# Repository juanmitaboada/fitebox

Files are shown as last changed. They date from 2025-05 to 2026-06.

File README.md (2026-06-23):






# FITEBOX - Autonomous Conference Recording Appliance

**Record every room. Spend almost nothing. Keep full control.**

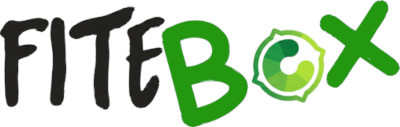
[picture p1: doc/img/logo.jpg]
Fitebox logo


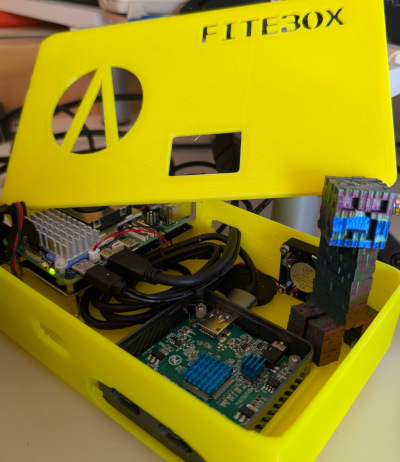
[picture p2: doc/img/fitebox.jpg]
Fitebox


**FITEBOX** is an open-source recording box built on a Raspberry Pi 5 that captures conference talks autonomously - composite video (slides + speaker camera), mixed audio, branded overlays, and optional live streaming to YouTube or Twitch - all managed from a tiny OLED screen on the box or a web UI on your phone.

One box per room. A volunteer plugs it in before the first talk, collects recordings at the end of the day. No dedicated operator, no laptop, no cloud dependency.

```
  License .... Apache 2.0
  Status ..... Production-ready - deploying at OpenSouthCode 2026, Málaga
  Authors .... Juanmi Taboada, David Santos
  Repository . https://github.com/juanmitaboada/fitebox
```

---

## Table of Contents

  1. [Why FITEBOX Exists](#1-why-fitebox-exists)
  2. [What You Get](#2-what-you-get)
  3. [Hardware Requirements](#3-hardware-requirements)
  4. [Quick Start](#4-quick-start)
  5. [Software Setup](#5-software-setup)
  6. [First Boot](#6-first-boot)
  7. [Documentation](#documentation) - Configuration, Recording, Streaming, Architecture, Troubleshooting, API
  8. [Project](#project) - Changelog, Contributing, Code of Conduct, Security Policy
  9. [Credits & Acknowledgments](#credits--acknowledgments)
  10. [License](#license)

---

## 1. Why FITEBOX Exists

Community tech conferences run on volunteer time and sponsor money. Recording talks is essential - speakers deserve an audience beyond the room, and attendees want to revisit sessions they missed - but professional recording services eat budgets alive. We know because it happened to us.

[OpenSouthCode](https://www.opensouthcode.org) is an annual open-source conference in Málaga, Spain. For years, hiring recording crews consumed up to **40% of the total event budget**. That is money not going to making the event better. For a non-profit association with limited funds, it was unsustainable.

In 2025, **David Santos** and **Juanmi Taboada** decided to fix this. David had the vision for the hardware: a small box based on a Raspberry Pi 5 with an OLED display and physical buttons, capable of autonomously recording a conference room. He designed the hardware architecture, selected the components (the SSD1306 OLED, the GPIO buttons, and the HDMI capture card - the same one used at FOSDEM conferences), and built the first physical prototype, including the 3D-printed enclosure. The hardware foundation of FITEBOX is David's work.

Both of us started developing software independently. We tried FFmpeg first, then OBS. We discovered the hard way that the Raspberry Pi 5 **has no hardware H.264 encoder** (the Pi 4 had `v4l2m2m` - the Pi 5 dropped it entirely). Cheap microphones died after 30 minutes. One of the units was handed to a volunteer with no user interface of any kind. OBS silently misconfigured itself. We lost nearly half the recordings from OpenSouthCode 2025.

But the idea was sound. One small box per room, fully autonomous, costing a fraction of a professional crew. After the event, Juanmi dove back in - this
time armed with patience, better tools, and a determination to make the Pi 5 work. Weeks of development followed: 36 versions of the recording engine, many manual tests on real hardware, and a complete web interface with real-time monitoring. FITEBOX grew from a rough experiment into a professional-grade recording and streaming system.

What you see in this repository is the result. It works. It has been tested.

**If your association, hackerspace, user group, or community conference needs to record talks without blowing the budget - this is for you.**

---

## 2. What You Get

All your videos properly recorded under a layout like this one:

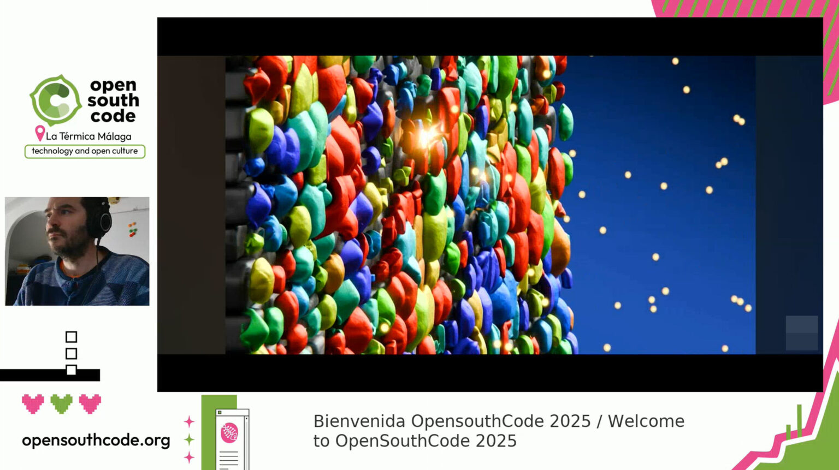
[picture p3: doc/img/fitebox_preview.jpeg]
Fitebox Video Layout


A fully configured FITEBOX gives you:

- **Composite 1080p recording** - presenter's screen (via HDMI capture) as the main image, speaker camera as picture-in-picture, your conference branding as the background frame, and talk title + speaker name as text overlays.

- **Automatic audio mixing** - room microphone plus HDMI audio from the presenter's laptop, combined automatically. Plug in one mic or two sources,
  the system adapts.

- **Crash-resistant MKV files** - recordings survive power failures. Even if someone trips over the power cable, everything recorded up to that point is
  recoverable.

- **Web UI from your phone** - read the 6-character access key from the OLED screen, type it in your phone browser, and you have full control: start/stop recording, monitor health, preview the feed, manage files, configure everything.

- **OLED + physical buttons** - no phone needed for basic operation. Navigate  menus, start recording, check status, all from four buttons on the box.

- **Live streaming** - optional RTMP streaming to YouTube, Twitch, or any custom server. Branded intro/outro bumpers, single persistent connection,
  zero extra CPU cost for video (audio re-encoded to fix timestamp issues).

- **Conference schedule integration** - import your Frab/Pentabarf schedule XML (the standard used by FOSDEM, CCC, OpenSouthCode, and many others) and FITEBOX auto-fills talk titles and speaker names based on room and time.

- **Network flexibility** - connect to the venue WiFi, create its own hotspot if there is no WiFi, or use Ethernet. All configurable from the web UI or
  OLED menus.

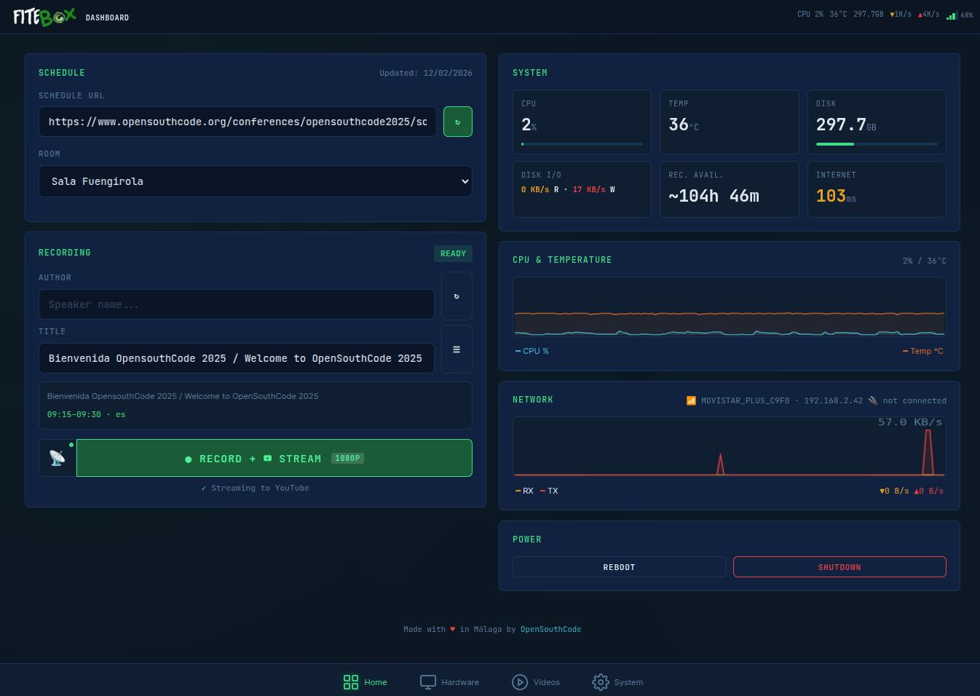
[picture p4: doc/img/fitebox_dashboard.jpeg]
Fitebox Web UI Dashboard


---

## 3. Hardware Requirements

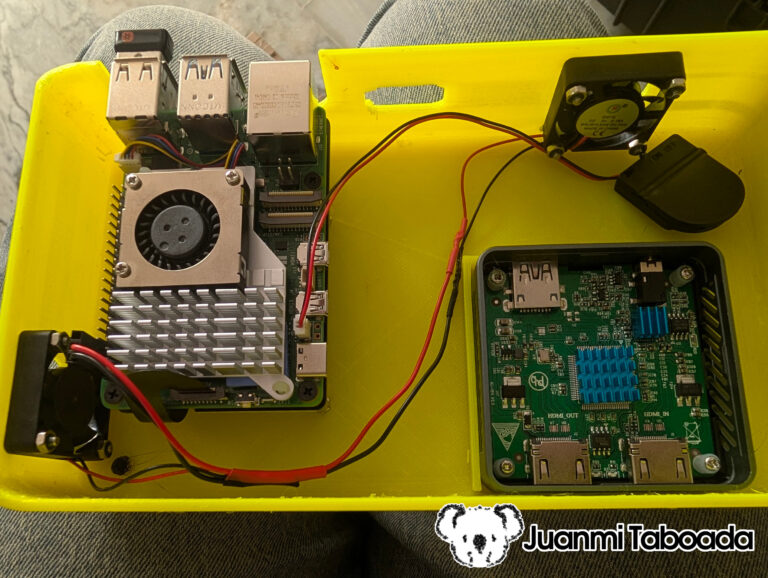
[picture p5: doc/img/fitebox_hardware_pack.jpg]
Fitebox Core Hardware


For a complete guide on assembling the hardware (mounting the NVMe HAT, installing the OLED+buttons module, building the enclosure), see the
companion build guide: [FITEBOX Build Guide - juanmitaboada.com](https://www.juanmitaboada.com/fitebox/)

---

## 4. Quick Start

If your hardware is assembled and your Raspberry Pi 5 is running **Raspberry Pi OS Lite (64-bit, Bookworm)**, this is all you need.

**1. Create the FITEBOX user** (from any account with sudo privileges — e.g. the default `pi` user):

```bash
sudo adduser osc
sudo usermod -aG sudo osc
```

> ⚠️ The user needs to be in the `sudo` group during installation. After the first boot, `setup.sh` automatically restricts sudo to only `reboot` and `shutdown` — no password needed for those.

**2. Log in as the new user:**

```bash
su - osc
# or reconnect via SSH as osc
```

**3. Download and run the installer:**

```bash
curl -fsSL https://raw.githubusercontent.com/juanmitaboada/fitebox/main/bin/install.sh -o install.sh
sudo bash install.sh
```

To install a specific version instead of `latest`:

```bash
sudo bash install.sh 1.2
sudo bash install.sh 1.2-rc1
```

The installer will:
- Download all required files (`setup.sh`, `docker-compose.yml`, `nginx.conf`)
- Install Docker, configure audio, optimize the kernel, and generate TLS certificates
- Pull the FITEBOX Docker image
- Start the containers
- Reboot the system (the OLED and display will show a reboot screen)

After reboot, FITEBOX starts automatically. Access the web UI at `https://<your-rpi-ip>`.

**To update to a new version**, use the web UI (System → Check for updates):

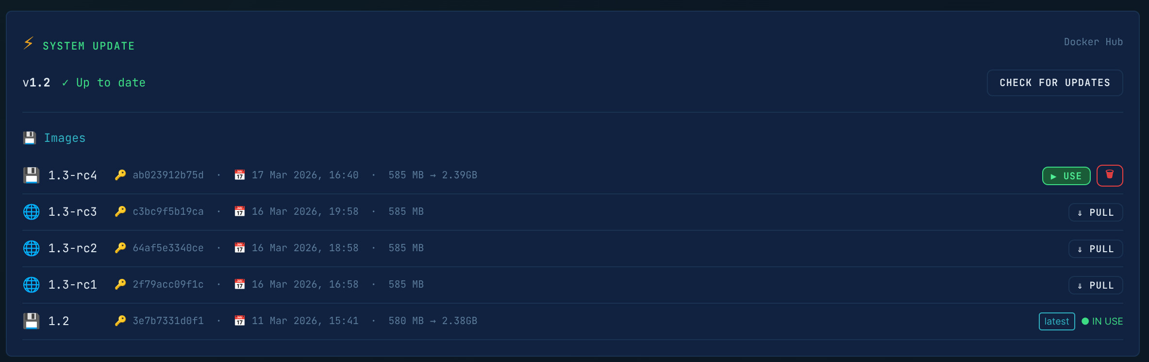
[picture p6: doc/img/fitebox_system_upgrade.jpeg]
Fitebox Upgrading System


**or run:**

```bash
cd ~/fitebox
docker compose pull
docker compose up -d
```

**To pin a specific version or test a pre-release**, edit `~/fitebox/docker-compose.yml` and change the image tag, then recreate the container:

```yaml
# Docker Hub
image: docker.io/br0th3r/fitebox:1.2
# GitHub Container Registry
image: ghcr.io/juanmitaboada/fitebox:1.2
# Pre-release
image: docker.io/br0th3r/fitebox:1.3-rc4
```

```bash
docker compose up -d --force-recreate recorder
```

Pre-release tags (`-rc`, `-beta`, `-alpha`, `-dev`) are published alongside stable releases but never replace `latest`.

---

## 5. Software Setup

### 5.1 Flash OS directly to the NVMe SSD

FITEBOX boots directly from the NVMe SSD - no SD card needed for daily use. Connect the NVMe SSD (via a USB adapter or the PCIe HAT on another Pi) and flash **Raspberry Pi OS Lite (64-bit, Debian 12 Bookworm)** to it using [Raspberry Pi Imager](https://www.raspberrypi.com/software/).

During setup in the Imager, enable:

- SSH (so you can work headless)
- Set hostname to something identifiable (e.g., `fitebox-room1`)
- Configure WiFi if needed for initial setup

After flashing, boot the Pi with a temporary SD card to configure PCIe and boot order:

```bash
sudo raspi-config
# → Advanced Options → PCIe Speed → Yes
#   (Enables the PCIe connector and forces Gen 3.0 speeds)

sudo raspi-config
# → Advanced Options → Boot Order → B1: SD Card Boot
#   (Boot from SD card if available, otherwise boot from NVMe)
```

Once configured, remove the SD card and the Pi boots from NVMe. Fast, reliable, and the full 500GB is available for both the OS and recordings.

SSH in and update:

```bash
sudo apt update && sudo apt upgrade -y
```

### 5.2 Enable I2C (for the OLED display)

> ✅ `setup.sh` now enables I2C automatically (`raspi-config nonint do_i2c 0`),
> so on a normal install you can skip this step. Do it by hand only if you need
> the OLED working **before** running `setup.sh`.

```bash
sudo raspi-config
# → Interface Options → I2C → Enable
```

Verify the OLED is detected (should show address `0x3c`):

```bash
sudo apt install -y i2c-tools
i2cdetect -y 1
```

The OLED+buttons integrated module connects to the GPIO header with an 8-wire ribbon cable:

| Module Pin | RPi Pin | GPIO |
|---|---|---|
| GND | 39 | Ground |
| VCC | 1 | 3.3V |
| SCL | 5 | GPIO3 (I²C) |
| SDA | 3 | GPIO2 (I²C) |
| K4 (Select) | 35 | GPIO19 |
| K3 (Down) | 38 | GPIO20 |
| K2 (Up) | 36 | GPIO16 |
| K1 (Back) | 37 | GPIO26 |

No external resistors needed - buttons use internal pull-ups via `gpiod`.

### 5.3 Create the recordings directory

Since the OS and recordings live on the same NVMe SSD, just create the recordings directory on the root filesystem:

```bash
sudo mkdir -p /recordings
sudo chown -R 1000:1000 /recordings
```

### 5.4 Build from Source (for development)

```bash
sudo apt-get install git
git clone https://github.com/juanmitaboada/fitebox.git
cd fitebox
make setup          # or: sudo ./bin/setup.sh
```

> ⚠️ **`make setup` is mandatory before your first `make up`.** Besides installing
> dependencies and configuring the Raspberry Pi, it **generates the self-signed TLS
> certificate** (`certs/fitebox.crt` / `certs/fitebox.key`) that the nginx proxy
> mounts. `make up` does **not** create it. If you skip setup and run `make up`
> directly, the `fitebox_proxy` container crash-loops with:
>
> ```
> nginx: [emerg] cannot load certificate "/etc/nginx/certs/fitebox.crt": ... No such file or directory
> ```
>
> (If you only need the certificate and not a full re-setup, generate it by hand:
> `mkdir -p certs && openssl req -x509 -nodes -days 3650 -newkey rsa:2048
> -keyout certs/fitebox.key -out certs/fitebox.crt -subj "/CN=fitebox.local"`.)

**A reboot is required** after setup ([what setup.sh does](#55-what-setupsh-does)).

After reboot, build and run:

```bash
make up_build       # build + start   (or: docker compose build && docker compose up -d)
```

From then on, `make up` / `make down` / `make logs` start, stop, and monitor the stack.

To publish your local build to the registries (maintainers only):

```bash
make publish
```

---

### 5.5 What setup.sh does

The setup script must be run with `sudo`. It detects the real user (via
`$SUDO_USER`) and performs the following:

1. Installs base tools: `curl`, `wget`, `git`, `build-essential`, `v4l-utils`,
   `alsa-utils`, `bc`, `jq`, and `i2c-tools` (for OLED detection with
   `i2cdetect`).
2. Installs Docker and the Compose plugin, adds your user to the `docker` group.
3. Disables PulseAudio and PipeWire system-wide (masks services, disables
   autospawn) so they do not block ALSA access.
4. Tunes USB buffers (`usbfs_memory_mb=1000`), kernel parameters
   (`vm.swappiness=10`, dirty ratios, scheduler), and file limits (65536).
5. Enables the **I2C** interface (required for the SSD1306 OLED at `0x3c`).
6. Configures the kernel command line (`cmdline.txt`): cgroups for Docker
   memory management, forced **HDMI output at 1080p60**, and a clean appliance
   display (no kernel logo, no blinking console cursor).
7. On Raspberry Pi 5: enables **PCIe Gen 3** for faster SSD throughput, forces
   the **4K page-size kernel** (`kernel=kernel8.img`) for software
   compatibility, and sets boot to console login required (disables autologin).
8. Installs the FITEBOX Plymouth boot splash theme (if `plymouth/` directory
   exists).
9. Configures passwordless sudo for `reboot`, `shutdown`, and Plymouth
   messages.
10. Creates the directory structure (`recordings/`, `log/`, `run/`) with
    correct ownership.
11. Generates self-signed TLS certificates for HTTPS.
12. Creates the `.env` file with your UID/GID so Docker containers create
    files owned by your user (not root).

All boot-file changes are **idempotent** — each parameter is added only if it is
missing, so the script is safe to re-run. See
[5.6 Boot configuration](#56-boot-configuration-what-each-parameter-does-and-why)
for what every parameter does and why.

### Container details

The container starts in **privileged mode** - it needs direct access to video
devices (`/dev/video*`), I2C (`/dev/i2c-*`), GPIO (`/dev/gpiochip*`), ALSA
audio (`/dev/snd/*`), and thermal sensors. This is not optional.

Persistent data is stored in Docker volumes mapped to:

| Volume | Purpose |
|---|---|
| `/recordings` | NVMe SSD - recorded files go here |
| `/fitebox/data` | Background image, bumpers, schedule, config |
| `/fitebox/config` | Authentication master key |
| `/fitebox/run` | Runtime state (sockets, PIDs, health) |
| `/fitebox/log` | Service logs |

### 5.6 Boot configuration: what each parameter does, and why

`setup.sh` manages two firmware files on the boot partition. It never rewrites
them wholesale and **never touches `root=` / `PARTUUID`** (that value is unique
to each SD card / SSD). Every parameter below is added **idempotently** — only
if it is missing — so re-running the script never duplicates anything.

**`/boot/firmware/config.txt`**

| Parameter | What it does | Why FITEBOX needs it |
|---|---|---|
| `dtparam=i2c_arm=on` | Enables the I2C bus on the GPIO header. | The SSD1306 OLED talks over I2C (address `0x3c`). Without it the `oled_controller` service cannot find the screen and dies on boot. |
| `dtparam=pciex1_gen=3` | Forces the PCIe connector to Gen 3 speed (RPi 5). | Full NVMe SSD throughput, so recording and disk writes never become the bottleneck. |
| `kernel=kernel8.img` | Loads the generic ARM64 kernel with a **4K** memory page size instead of the Pi 5 default `kernel_2712.img`, which uses **16K** pages. | The 16K-page kernel buys ~5% performance but breaks software that assumes 4K pages (segmentation faults, "unsupported page size", or programs refusing to start). FITEBOX's FFmpeg / V4L2 capture / Python stack is built and tested on 4K pages, so the tiny performance trade-off is well worth the stability. Verify after reboot with `getconf PAGESIZE` → `4096` = correct, `16384` = wrong kernel. |

**`/boot/firmware/cmdline.txt`** — a **single line**; parameters are
space-separated and appended to the end:

| Parameter | What it does | Why FITEBOX needs it |
|---|---|---|
| `cgroup_enable=cpuset cgroup_enable=memory cgroup_memory=1` | Enables memory/cpuset cgroups in the kernel. | Docker needs them to enforce per-container memory limits. |
| `video=HDMI-A-1:1920x1080M@60` | Pins the HDMI output to 1080p @ 60 Hz. | The display daemon owns the HDMI port for status screens; without a fixed mode the resolution is auto-negotiated and may come up wrong or blank on some monitors. |
| `logo.nologo` | Hides the Raspberry Pi kernel logos shown during boot. | A clean, appliance-like boot — no Linux branding on the projector. |
| `vt.global_cursor_default=0` | Disables the blinking text cursor on the console. | Stops the lone blinking cursor from showing through on the HDMI output between the boot splash and the application. |

> ℹ️ **Why not just edit the files by hand?** Because each box may have a
> different `PARTUUID`, a different monitor, and may be re-imaged often.
> `setup.sh` adds only the keys that are missing and leaves everything else —
> most importantly `root=` — untouched, so it is safe to run on any fresh image.
> A **reboot** is required for kernel-page-size, PCIe and `cmdline.txt` changes
> to take effect.

### 5.8 Diagnostics

Before your first recording, run the diagnostic tools to verify all hardware is detected:

```bash
# Full system diagnostic - generates a timestamped report in /tmp/
./src/diagnostics.sh

# Audio device detection - classifies all ALSA cards by type
./src/detect_audio.sh

# OLED display detection - scans I2C, runs visual tests
./src/detect_oled.sh

# Button test - verifies GPIO button wiring
python3 src/detect_buttons.py
```

`diagnostics.sh` checks: system info, Raspberry Pi thermal/throttle status, disk space, USB devices, video devices (`v4l2-ctl`), audio devices and levels,
PulseAudio/PipeWire status (should be disabled), I2C/OLED, running FITEBOX processes, Docker containers, health files, recent logs, kernel messages,
network, and CPU/memory. It works both on the host and inside the container.

`detect_audio.sh` classifies ALSA cards into categories (`hdmi_capture`, `webcam`, `sound_card`, `usb_mic`, `generic_usb`) and selects the best
microphone with a priority order: professional sound card > USB mic > generic USB > webcam (fallback). It has a dual mode: run it directly for a full
diagnostic, or source it from another script (like the recording engine) and it exports variables (`VOICE_DEV`, `HDMI_DEV`, `VOICE_CARD_ID`, etc.)
silently. If the HDMI capture and voice mic end up being the same device (which would cause "Device or resource busy"), it automatically disables
HDMI audio and falls back to voice-only mode.

`detect_oled.sh` scans the I2C bus, finds the OLED at `0x3C` or `0x3D`, checks Python dependencies (`luma.oled`, `Pillow`), and runs a series of
visual tests on the display: clear screen, full white, border, text, animation, and a final info screen. It even stops `oled_controller.py` if it is running (the OLED can only be controlled by one process) and restarts it afterwards.

`detect_buttons.py` uses the FiteboxHardware abstraction to test all 4 GPIO buttons in real-time - press a button and see it reported on screen with
PRESS/RELEASE events at 100Hz polling.

---

## 6. First Boot

When the container starts, four services come up in order:

1. **Display daemon** - takes over the HDMI output for status screens and announcements.
2. **OLED controller** - the display lights up with the FITEBOX logo, then shows the system status.
3. **FITEBOX manager** - starts polling hardware (CPU, temperature, disk, network) and broadcasting status.
4. **Web server** - FastAPI on port 8080, ready for connections.

### Reading the access key

Look at the OLED screen. Cycle through the status views using the Up/Down buttons until you see the **Web Key** screen. It shows a 6-character hex code
like `A1B2C3`.

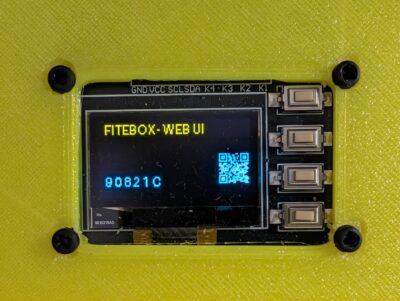
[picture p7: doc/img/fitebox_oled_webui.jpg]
Fitebox OLED Web UI Key


### Connecting to the web UI

On your phone or laptop, make sure you are on the same network as the FITEBOX (or connect to its hotspot if it created one). Open a browser and go to:

```
https://<FITEBOX_IP>
```

The OLED can also show a QR code with this URL - scan it with your phone camera for instant access.

Enter the 6-character key. You are in.

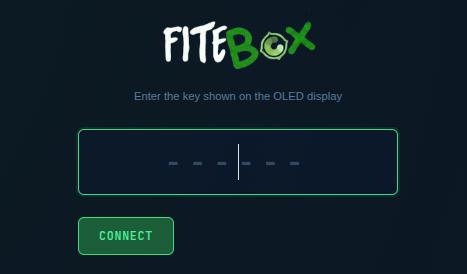
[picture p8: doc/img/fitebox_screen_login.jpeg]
Fitebox Web UI Login


---

## Documentation

  - [Configuration](doc/configuration.md) - Network, schedule, background, bumpers, diagnostics, security, self-update
  - [Recording a Talk](doc/recording.md) - Web UI, OLED buttons, engine internals, monitoring, announcements to projector
  - [Live Streaming](doc/streaming.md) - YouTube, Twitch, custom RTMP, single-connection architecture
  - [Managing Recordings](doc/recordings.md) - Playback, download, bumper concatenation, batch operations
  - [Architecture](doc/architecture.md) - Container layout, process communication, design decisions
  - [Troubleshooting](doc/troubleshooting.md) - Power, video, audio, encoding, OLED, USB, recovery
  - [API Reference](doc/api.md) - REST endpoints, WebSocket protocol, HMAC authentication
  - [Diagnostics Guide](doc/diagnostics.md) - How to use the diagnostic tools, interpret results, and fix common issues

---

## Project

  - [Changelog](CHANGELOG.md)
  - [Contributing](CONTRIBUTING.md)
  - [Code of Conduct](CODE_OF_CONDUCT.md)
  - [Security Policy](SECURITY.md)

---

## Credits & Acknowledgments

**David Santos** - designed the hardware architecture for the first FITEBOX prototype, selected the OLED display and button components, selected the HDMI capture card (the same one used at FOSDEM conferences), built the preliminary OLED controller software, and designed and 3D-printed the first physical enclosure (STL files included in the repository). The hardware foundation of this project exists because of David's work.

**Juanmi Taboada** - software development: recording engine (36 versions), streaming pipeline, web interface, system manager, OLED controller v2+, CPU optimization, setup automation, and all the FFmpeg debugging that led to production stability.

**[OpenSouthCode](https://www.opensouthcode.org)** - the annual open-source conference in Málaga, Spain, where FITEBOX was conceived, developed, and will be deployed in production at the 2026 edition. The need to record every room affordably and reliably is the reason this project exists.

This project was developed with assistance from AI coding tools (Claude by Anthropic, Gemini by Google) as pair-programming partners during the development process.

**Build guide & full story:** [juanmitaboada.com/fitebox](https://www.juanmitaboada.com/fitebox/)

**Docker images:** [GitHub Container Registry](https://ghcr.io/juanmitaboada/fitebox) · [Docker Hub](https://hub.docker.com/r/juanmitaboada/fitebox)

---

## License

```
Copyright 2025-2026 Juanmi Taboada, David Santos

Licensed under the Apache License, Version 2.0 (the "License");
you may not use this file except in compliance with the License.
You may obtain a copy of the License at

    http://www.apache.org/licenses/LICENSE-2.0

Unless required by applicable law or agreed to in writing, software
distributed under the License is distributed on an "AS IS" BASIS,
WITHOUT WARRANTIES OR CONDITIONS OF ANY KIND, either express or implied.
See the License for the specific language governing permissions and
limitations under the License.
```

---

*FITEBOX - because every talk deserves to be recorded, and no community
should go broke doing it.*

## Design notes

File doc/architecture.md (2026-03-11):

[← README](../README.md) · [Configuration](configuration.md) · [Recording](recording.md) · [Streaming](streaming.md) · [Recordings](recordings.md) · 【 **Architecture** 】 · [Troubleshooting](troubleshooting.md) · [API](api.md) · [Diagnostics](diagnostics.md)

## Architecture Overview

FITEBOX runs as two Docker Compose services. The main container holds all
application logic; a second container provides HTTPS termination:

| Service | Container | Role |
|---|---|---|
| `recorder` | `fitebox-recorder` | Main app — privileged, all FITEBOX logic |
| `proxy` | `fitebox-proxy` | nginx:alpine — HTTPS + WebSocket proxy |

Inside the **recorder** container, Supervisord manages four long-running
processes. The recording engine is launched on demand as a subprocess:

```
fitebox-recorder (privileged, network_mode: host)
│
│  Supervisord
│  ├── fitebox_display.py   ── Framebuffer display daemon (/dev/fb0)
│  ├── oled_controller.py   ── OLED + GPIO + Unix socket SERVER (hub)
│  ├── fitebox_manager.py   ── coordinator, launches recording engine
│  └── fitebox_web.py       ── FastAPI :8080, REST + WebSocket
│
│  On demand (subprocess of manager):
│  └── recording_engine.sh  ── FFmpeg composite → MKV + health.json
│
│  Communication:
│  oled_controller   ←── serves ──→  Unix Socket (.sock)
│  fitebox_manager   ←── client ──→  Unix Socket
│  fitebox_web       ←── client ──→  Unix Socket
│  fitebox_display   ←── serves ──→  Display Socket (.sock)
│  fitebox_web       ←── reads  ──→  MKV files + health.json
│
fitebox-proxy (nginx:alpine)
│  443 (HTTPS) → proxy_pass → 127.0.0.1:8080
│  80  (HTTP)  → redirect   → 443
```

The **OLED controller** owns the Unix domain socket and acts as the message
hub. The manager and web server connect as clients. When the manager sends a
status update, the OLED controller broadcasts it to all connected clients,
including the web server which pushes it to browsers via WebSocket.

The **display daemon** manages the HDMI output via `/dev/fb0`, replacing
Plymouth for runtime screen management. It pre-loads all screen images at
startup using numpy-accelerated RGB565 conversion (~0.3s), then idles at 0%
CPU until a message arrives on its Unix socket. It supports screen changes,
text overlays, and announcement overlays with flashing borders and
auto-scaled text.

The **manager** launches the recording engine as a subprocess on demand. The
web server reads from the MKV file and health logs produced by the engine
(for preview, health histogram, and streaming) but does not control it
directly.

**Key design decisions:**

**Why MKV?** Because it is the most crash-resistant container format. FFmpeg
writes Matroska clusters incrementally. If the process dies, you lose at most
the last few seconds, not the entire file.

**Why not microservices?** A Raspberry Pi is not a Kubernetes cluster. One
container with all services, communicating over a Unix socket, is simpler to
deploy, debug, and maintain. It starts faster and uses less memory.

**Why `ultrafast` preset?** The Pi 5 CPU is barely fast enough for real-time
1080p software encoding. The `ultrafast` preset trades file size for encoding
speed. At CRF 28 the quality is good enough for conference recordings and the
bitrate (~2.4 Mbps) is modest.

**Why software encoding at all?** Because the Raspberry Pi 5 has no hardware
H.264 encoder. The Pi 4 had `v4l2m2m` but the Pi 5 dropped it. This is the
single biggest design constraint of the entire project.

[← README](../README.md) · [Configuration](configuration.md) · [Recording](recording.md) · [Streaming](streaming.md) · [Recordings](recordings.md) · 【 **Architecture** 】 · [Troubleshooting](troubleshooting.md) · [API](api.md) · [Diagnostics](diagnostics.md)

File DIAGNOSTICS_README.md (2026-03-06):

# FITEBOX - Universal Diagnostics System

## Overview

The `diagnostics.sh` script works both on the **host** (Raspberry Pi) and inside the **Docker container**.

It auto-detects its environment and adapts the available commands accordingly.

---

## Usage

### On the HOST (Raspberry Pi):

```bash
cd ~/fitebox
./src/diagnostics.sh
```

### Inside the CONTAINER:

```bash
# Option 1: Execute from the host
docker exec fitebox-recorder /app/diagnostics.sh

# Option 2: Enter the container
docker exec -it fitebox-recorder bash
./diagnostics.sh
```

---

## What It Checks

### Always available (host + container):
- System information (OS, kernel, CPU, RAM)
- Disk space
- FITEBOX processes (FFmpeg, manager, OLED, web server)
- State files and logs
- Network configuration
- CPU/memory usage

### Host only:
- Raspberry Pi status (temperature, throttling, voltage)
- systemd services
- System configuration (PulseAudio, USB buffers)
- Docker container status

### Container only:
- Container environment info
- Volume mounts

### Requires privileges/devices:
- USB devices (`lsusb`) → requires `/dev/bus/usb`
- Video devices (`v4l2-ctl`) → requires `/dev/video*`
- Audio devices (`arecord`, `amixer`) → requires `/dev/snd`
- I2C (`i2cdetect`) → requires `/dev/i2c-*`
- Kernel messages (`dmesg`) → requires `CAP_SYSLOG`

---

## Docker Configuration

### Required system packages (in Dockerfile):
- `bc` - calculations for monitor
- `jq` - JSON parsing
- `usbutils` - lsusb
- `v4l-utils` - v4l2-ctl
- `alsa-utils` - arecord, amixer
- `i2c-tools` - i2cdetect
- `net-tools` - ifconfig
- `iproute2` - ip

### docker-compose.yml requirements:

**Device access:**
```yaml
devices:
  - /dev/video0:/dev/video0  # Cameras
  - /dev/snd:/dev/snd        # Audio
  - /dev/i2c-1:/dev/i2c-1    # OLED
  - /dev/gpiomem:/dev/gpiomem # Buttons
```

**Volumes for diagnostics:**
```yaml
volumes:
  - /dev/bus/usb:/dev/bus/usb:ro  # USB info
  - /proc:/host/proc:ro            # System info
  - /sys:/host/sys:ro              # Hardware info
  - /tmp:/host/tmp                 # Shared logs
```

**Privileged mode:**
```yaml
privileged: true  # Full hardware access
```

---

## Output

The script generates a timestamped report in `/tmp/`:
```
/tmp/fitebox_diagnostic_YYYYMMDD_HHMMSS.txt
```

### View from the host:
```bash
# If executed inside the container
docker exec fitebox-recorder cat /tmp/fitebox_diagnostic_*.txt

# Copy to host
docker cp fitebox-recorder:/tmp/fitebox_diagnostic_20260206_120000.txt .
```

---

## Troubleshooting

### Problem: "lsusb failed"
**Solution**: Verify `/dev/bus/usb` is mounted:
```bash
docker exec fitebox-recorder ls -la /dev/bus/usb
```

### Problem: "v4l2-ctl failed"
**Solution**: Verify video devices:
```bash
docker exec fitebox-recorder ls -la /dev/video*
```

### Problem: "arecord failed"
**Solution**: Verify `/dev/snd`:
```bash
docker exec fitebox-recorder ls -la /dev/snd
```

### Problem: "dmesg not accessible"
**Solution**: This is normal inside a container without `CAP_SYSLOG`. Run on the host instead:
```bash
dmesg | grep -i fitebox
```

---

## Rebuilding the Container

After updating the Dockerfile:

```bash
cd ~/fitebox

# Stop containers
docker compose down

# Rebuild
docker compose build --no-cache

# Start
docker compose up -d

# Verify
docker exec fitebox-recorder /app/diagnostics.sh
```

---

## Validation

### Quick test:

```bash
# On the host
./src/diagnostics.sh | grep "Environment:"
# Should show: Environment: host

# In the container
docker exec fitebox-recorder /app/diagnostics.sh | grep "Environment:"
# Should show: Environment: container
```

### Commands that MUST work in both environments:

| Command | Host | Container |
|---|---|---|
| Basic system info | ✅ | ✅ |
| Disk space | ✅ | ✅ |
| Processes | ✅ | ✅ |
| Network | ✅ | ✅ |
| `lsusb` | ✅ | ✅* |
| `v4l2-ctl` | ✅ | ✅* |
| `arecord` | ✅ | ✅* |
| `i2cdetect` | ✅ | ✅* |
| `vcgencmd` | ✅ | ❌ |
| `systemctl` | ✅ | ❌ |

\* Requires devices mounted correctly

---

## Usage Examples

```bash
# 1. Run full diagnostic
docker exec fitebox-recorder /app/diagnostics.sh

# 2. Search for specific problems
docker exec fitebox-recorder /app/diagnostics.sh | grep -i "error\|fail\|warn"

# 3. Audio devices only
docker exec fitebox-recorder /app/diagnostics.sh | grep -A 20 "AUDIO DEVICES"

# 4. Video devices only
docker exec fitebox-recorder /app/diagnostics.sh | grep -A 20 "VIDEO DEVICES"

# 5. Save and share
docker exec fitebox-recorder /app/diagnostics.sh > diagnostic_$(date +%Y%m%d).txt
```

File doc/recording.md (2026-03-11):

[← README](../README.md) · [Configuration](configuration.md) · 【 **Recording** 】 · [Streaming](streaming.md) · [Recordings](recordings.md) · [Architecture](architecture.md) · [Troubleshooting](troubleshooting.md) · [API](api.md) · [Diagnostics](diagnostics.md)

## Recording a Talk

### From the web UI

1. Open the **Dashboard**.
2. Verify the current talk is shown (if schedule is loaded).
3. Verify cameras and audio on the **Hardware** page - you can see live MJPEG previews of both cameras and audio level meters, all at zero CPU cost.
4. Go back to Dashboard, hit the big **Start Recording** button.

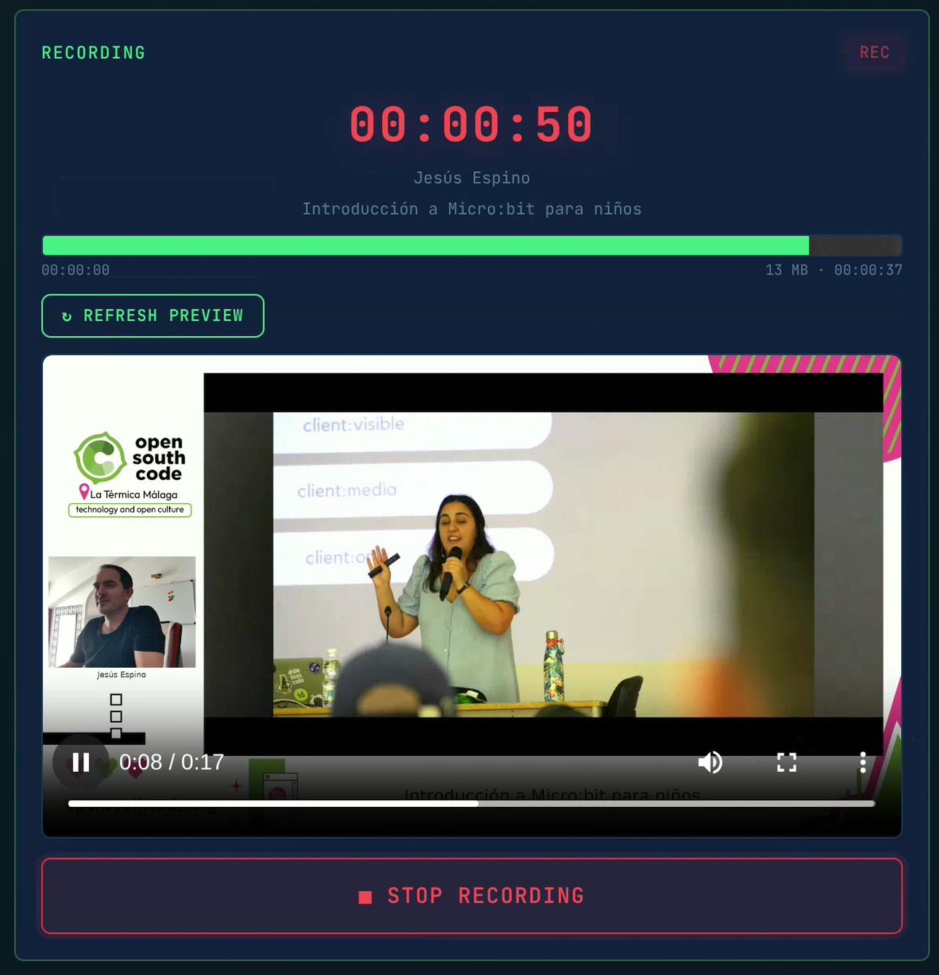
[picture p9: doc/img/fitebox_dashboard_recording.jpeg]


### From the physical buttons

Navigate the OLED menu to the recording option and press Select. The OLED will show recording status (elapsed time, file size) while it runs.

### What happens under the hood

The recording engine (v36) launches a single long-running FFmpeg process that:

1. Reads three video inputs simultaneously: your background PNG, the HDMI capture card, and the USB webcam.
2. Composites them into the 1920×1080 layout described above.
3. Overlays the speaker name and talk title as text.
4. Mixes audio from all detected sources (room mic + HDMI audio if available).
5. Encodes to H.264 (software, `libx264 -preset ultrafast -crf 28`) and AAC audio.
6. Writes to a **Matroska (.mkv)** container on the SSD.

MKV was chosen deliberately for crash resistance: even if power is cut mid-recording, all data up to that point is recoverable.

Output specs:

```
  Container .. MKV (Matroska)
  Video ...... H.264, Constrained Baseline, 1920x1080, 30fps, CRF 28
  Audio ...... AAC LC, 192 kbps, 48 kHz, stereo
  Bitrate .... ~2.4 Mbps total (~1 GB/hour)
  Storage .... 500GB NVMe ≈ 500 hours of recording
  Filename ... rec_YYYYMMDD_HHMMSS[_Author_Title].mkv
```

### Monitoring a recording

While recording, the dashboard shows:

- **Health histogram** - live FFmpeg stats: fps, bitrate, encoding speed, dropped frames. If speed drops below 1.0x, you have a problem.
- **Recording preview** - a ~15-second clip extracted from the growing MKV file using the "sandwich" technique, playable directly in the browser.
- **CPU and temperature charts** - 10-minute sparkline so you can spot thermal throttling.
- **Disk I/O and remaining time estimate**.

### Stopping

Hit Stop on the dashboard or press the button on the box. FFmpeg receives a clean shutdown signal, finalizes the MKV headers, and the file is ready.

### Announcements (projector messages)

During a talk, the session chair often needs to signal the speaker: "5 minutes left", "Q&A time", etc. FITEBOX can display these messages directly on the projector screen, overlaid on whatever is being shown.

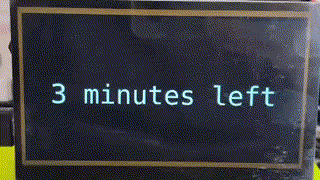
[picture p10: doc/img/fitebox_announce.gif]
Fitebox Announce


From the **Dashboard**, the Announce card provides:

- A **text input** for custom messages (type anything and hit Enter or the send button).
- A **preset selector** with common messages in the language of the current talk (detected from the conference schedule). Presets include: ready to begin, time warnings (10/5/3/1 min), Q&A, and thank you.

From the **OLED**, navigate to System → Announce to select the same presets using the physical buttons.

When triggered, the message appears full-screen on the HDMI output with a **flashing yellow border** and auto-scaled white text on a dark background. The overlay lasts 10 seconds, then the display automatically returns to its previous state (recording screen, ready screen, etc.). Messages sent to the display during the overlay are queued and applied when it ends.

The web UI shows a "● LIVE" countdown badge while an announcement is active, preventing duplicate sends.

[← README](../README.md) · [Configuration](configuration.md) · 【 **Recording** 】 · [Streaming](streaming.md) · [Recordings](recordings.md) · [Architecture](architecture.md) · [Troubleshooting](troubleshooting.md) · [API](api.md) · [Diagnostics](diagnostics.md)

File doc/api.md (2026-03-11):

[← README](../README.md) · [Configuration](configuration.md) · [Recording](recording.md) · [Streaming](streaming.md) · [Recordings](recordings.md) · [Architecture](architecture.md) · [Troubleshooting](troubleshooting.md) · 【 **API** 】 · [Diagnostics](diagnostics.md)

## API Reference

The web server exposes a REST API with HMAC-SHA256 authentication. All requests must include a signature computed as `HMAC(timestamp:body, key)` with a 30-second replay window.

Key endpoints:

| Method | Path | Description |
|---|---|---|
| `POST` | `/api/recording/start` | Start recording (optional: author, title) |
| `POST` | `/api/recording/stop` | Stop recording |
| `POST` | `/api/streaming/start` | Start streaming (destination, key) |
| `POST` | `/api/streaming/stop` | Stop streaming |
| `GET` | `/api/recordings` | List recordings with metadata |
| `GET` | `/api/recordings/<file>/play` | Stream MKV→MP4 for browser playback |
| `GET` | `/api/recordings/<file>/download` | Download original MKV |
| `POST` | `/api/recordings/<file>/bumper` | Apply bumpers to recording |
| `DELETE` | `/api/recordings/<file>` | Delete recording |
| `GET` | `/api/hardware/preview/<device>` | MJPEG preview stream |
| `GET` | `/api/hardware/audio/<device>` | MP3 audio stream |
| `POST` | `/api/network/scan` | Scan WiFi networks |
| `POST` | `/api/network/connect` | Connect to WiFi |
| `POST` | `/api/network/hotspot` | Create WiFi hotspot |
| `POST` | `/api/schedule/download` | Download conference schedule XML |
| `GET/POST` | `/api/system/security` | Get/set OLED security restrictions |
| `POST` | `/api/system/announce` | Show message on projector (10s overlay) |
| `GET` | `/api/system/announce/presets` | Bilingual preset messages |
| `GET` | `/api/system/update/check` | Check for available updates |
| `POST` | `/api/system/update/start` | Start self-update process |
| `GET` | `/api/system/update/progress` | Update progress (percent, phase) |
| `POST` | `/api/system/reboot` | Reboot the Raspberry Pi |
| `POST` | `/api/system/shutdown` | Shut down the Raspberry Pi |
| `WS` | `/ws` | WebSocket — status updates, metrics, announce events |

The JavaScript client library (`fitebox.js`) handles HMAC signing, WebSocket reconnection, announce events, and toast notifications automatically.

[← README](../README.md) · [Configuration](configuration.md) · [Recording](recording.md) · [Streaming](streaming.md) · [Recordings](recordings.md) · [Architecture](architecture.md) · [Troubleshooting](troubleshooting.md) · 【 **API** 】 · [Diagnostics](diagnostics.md)

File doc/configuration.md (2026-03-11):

[← README](../README.md) · 【 **Configuration** 】 · [Recording](recording.md) · [Streaming](streaming.md) · [Recordings](recordings.md) · [Architecture](architecture.md) · [Troubleshooting](troubleshooting.md) · [API](api.md) · [Diagnostics](diagnostics.md)

## Configuration

All configuration is done from the **System** page in the web UI. Do this before the event.

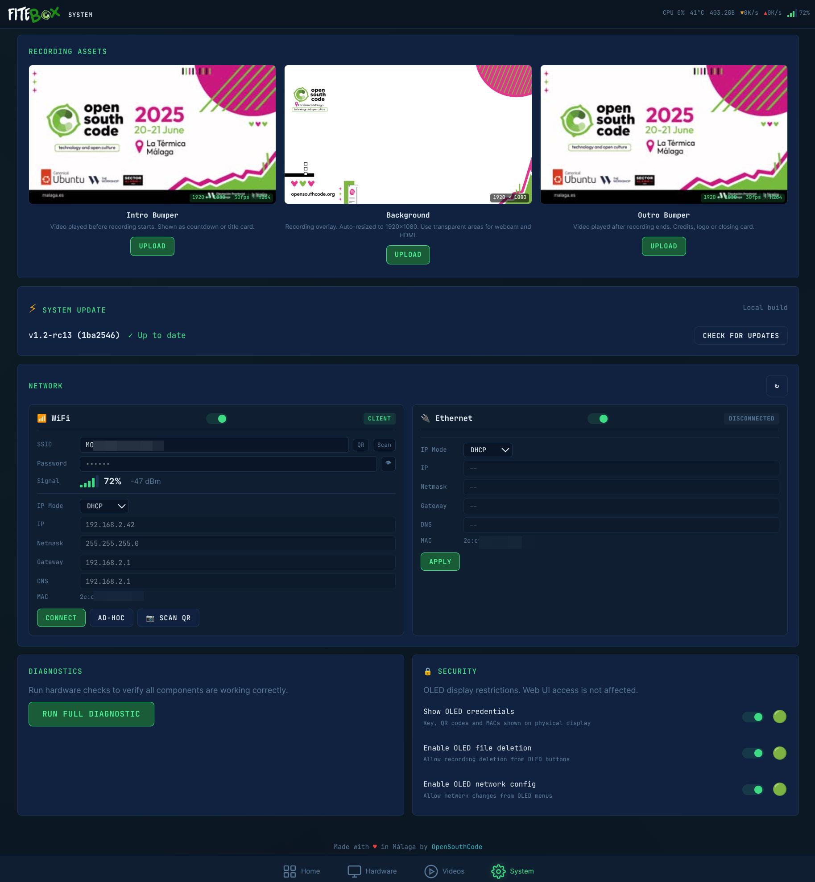
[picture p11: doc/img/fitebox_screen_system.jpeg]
Fitebox Web UI System


### Network

From the System page you can:

- Scan for WiFi networks and connect (supports open and WPA)
- Create a FITEBOX hotspot (`FITEBOX_AP`) for direct phone connection
- View Ethernet status
- Set static IP if your venue needs it

For live streaming, Ethernet is recommended. WiFi works fine for the web UI.

### Conference Schedule

If your conference uses **Frab/Pentabarf schedule format** (most open-source conferences do), paste the schedule URL and hit Download. Then select the room this FITEBOX is assigned to.

```
Example: https://www.opensouthcode.org/conferences/opensouthcode2025/schedule.xml
```

Once loaded, the dashboard will automatically show the current talk based on time and room. When you start recording, the speaker name and talk title are auto-filled and rendered as text overlays in the recording.

### Background Image

Upload a **1920×1080 PNG** that serves as the branded frame for your composite recording. This is the canvas behind the slides and speaker camera. Example:

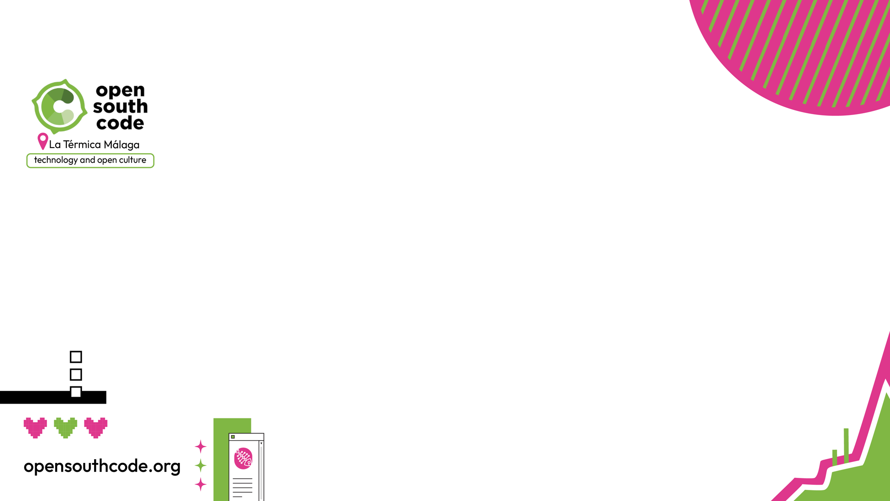
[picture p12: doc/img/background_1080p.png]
Fitebox Background Image


The composite layout:

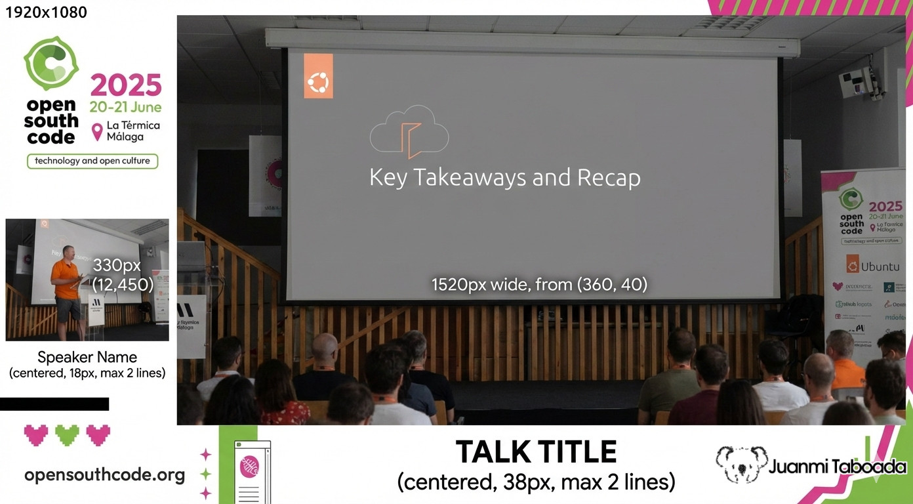
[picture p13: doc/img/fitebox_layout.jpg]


### Bumpers (Intro/Outro)

Upload optional branded video clips (your conference logo animation, sponsor reel, etc.) that will be prepended and appended to recordings.

The upload workflow:

1. Upload any video format.
2. FITEBOX probes it with ffprobe and shows you the specs.
3. If the format matches (1080p, 30fps, H.264, AAC 48kHz) → instant copy.
4. If it does not match → shows you the differences, you confirm, it re-encodes.
5. A thumbnail preview is extracted.

Bumpers are used in two places: as intro/outro segments during live streaming, and for offline concatenation with finished recordings.

### Diagnostics

The System page includes a diagnostics section that checks hardware, audio, video, network, and storage. Run it before the event to catch problems early. When a diagnostic runs, both the OLED and HDMI display show a notification.

### Security Settings

The Security panel on the System page controls what the OLED physical display reveals. This is useful when the box is in a public area and you don't want the access key or network details visible on the screen. Three toggles:

- **Show OLED credentials** — when disabled, the Web Access, Web UI QR, and About screens show a padlock instead of the key, QR codes, and MAC addresses.
- **Enable OLED file deletion** — when disabled, pressing the delete button on the OLED shows "Delete disabled" instead of the confirmation prompt.
- **Enable OLED network config** — when disabled, the Network menu on the OLED is blocked with a "Network locked" message.

Settings are persisted in `/fitebox/data/security.json` and survive reboots. Changes take effect immediately on the OLED. The web UI is never restricted by these settings.

### System Update

FITEBOX can update itself from the System page. It detects whether it was deployed from a pre-built Docker image (official mode) or built from source (local mode):

- **Official mode**: pulls the latest image from Docker Hub and recreates the container.
- **Local mode**: runs `git pull` on the project directory, rebuilds the Docker image, and recreates the container.

The OLED and HDMI display show a progress bar during the update. The web UI displays a full-screen restart overlay with progress and automatically reloads when the new container is ready. A sidecar container handles the actual restart (since the running container cannot restart itself).

[← README](../README.md) · 【 **Configuration** 】 · [Recording](recording.md) · [Streaming](streaming.md) · [Recordings](recordings.md) · [Architecture](architecture.md) · [Troubleshooting](troubleshooting.md) · [API](api.md) · [Diagnostics](diagnostics.md)

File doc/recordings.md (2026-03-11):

[← README](../README.md) · [Configuration](configuration.md) · [Recording](recording.md) · [Streaming](streaming.md) · 【 **Recordings** 】 · [Architecture](architecture.md) · [Troubleshooting](troubleshooting.md) · [API](api.md) · [Diagnostics](diagnostics.md)

## Managing Recordings

The **Recordings** page in the web UI lets you:

- Browse all recordings with metadata (duration, size, date, speaker, title)
- **Play back in the browser** - MKV files are remuxed to MP4 on-the-fly (zero CPU, just container repackaging)
- Download the original MKV
- **Apply bumpers** - concatenate intro + recording + outro into a single file with automatic A/V sync validation
- Batch delete with confirmation
- View JSON metadata sidecars

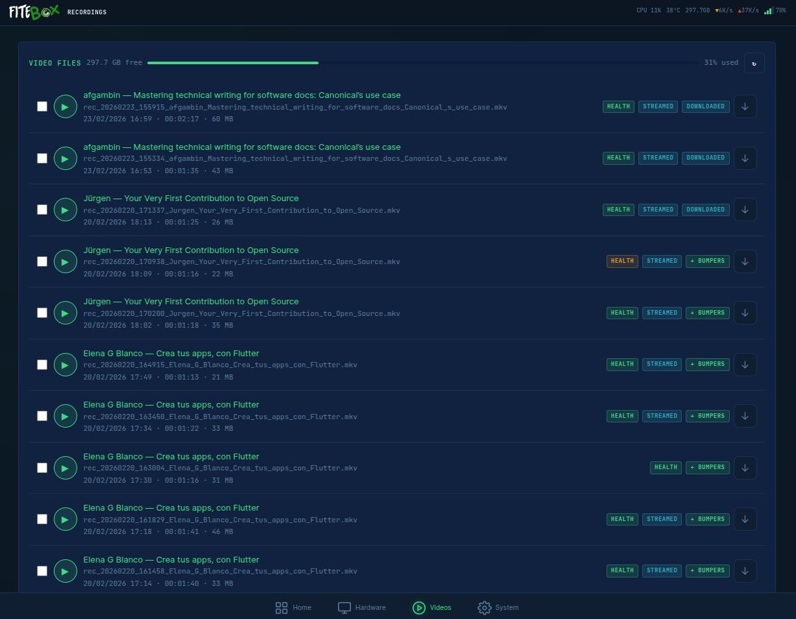
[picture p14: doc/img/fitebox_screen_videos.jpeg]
Fitebox Web UI Videos


[← README](../README.md) · [Configuration](configuration.md) · [Recording](recording.md) · [Streaming](streaming.md) · 【 **Recordings** 】 · [Architecture](architecture.md) · [Troubleshooting](troubleshooting.md) · [API](api.md) · [Diagnostics](diagnostics.md)

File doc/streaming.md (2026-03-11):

[← README](../README.md) · [Configuration](configuration.md) · [Recording](recording.md) · 【 **Streaming** 】 · [Recordings](recordings.md) · [Architecture](architecture.md) · [Troubleshooting](troubleshooting.md) · [API](api.md) · [Diagnostics](diagnostics.md)

## Live Streaming (Optional)

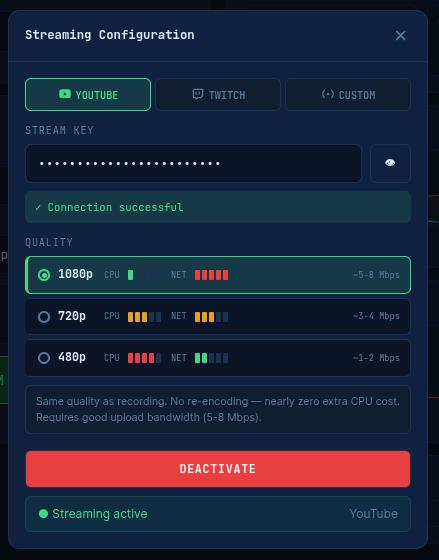
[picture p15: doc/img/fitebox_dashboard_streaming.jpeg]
Fitebox Live Streaming


FITEBOX can stream to YouTube, Twitch, or any RTMP server while simultaneously recording locally. This was one of the hardest parts to get right.

### Configuration

On the Dashboard, select a streaming destination (YouTube / Twitch / Custom) and enter your stream key. Hit Start Streaming after the recording is running.

### How it works

The streaming pipeline maintains a **single persistent RTMP connection** and feeds video segments sequentially:

```
  Phase 1 - WAITING ..... polls until recording starts
  Phase 2 - BUFFERING ... waits ~15s for MKV to accumulate data
  Phase 3 - INTRO ....... feeds the intro bumper
  Phase 4 - LIVE ........ feeds the growing MKV file (video: copy, audio: re-encode)
  Phase 5 - DRAINING .... recording stopped, drains to natural EOF
  Phase 6 - OUTRO ....... feeds the outro bumper
  Phase 7 - CLOSING ..... closes RTMP connection cleanly
```

The live phase uses **`-c:v copy`** for video - zero CPU cost. Only the audio is re-encoded to fix timestamp irregularities that would otherwise cause audible clicks on the stream (see Troubleshooting).

Timestamp continuity across phases is maintained with `-output_ts_offset` chaining on each feeder process. Without this, YouTube sees timestamp jumps and kills the stream.

### Why a single RTMP connection?

Multiple connections caused YouTube to interpret each segment as a separate stream. The audience would see "stream ended" and have to rejoin. One persistent TCP session through the entire broadcast solved this.

[← README](../README.md) · [Configuration](configuration.md) · [Recording](recording.md) · 【 **Streaming** 】 · [Recordings](recordings.md) · [Architecture](architecture.md) · [Troubleshooting](troubleshooting.md) · [API](api.md) · [Diagnostics](diagnostics.md)

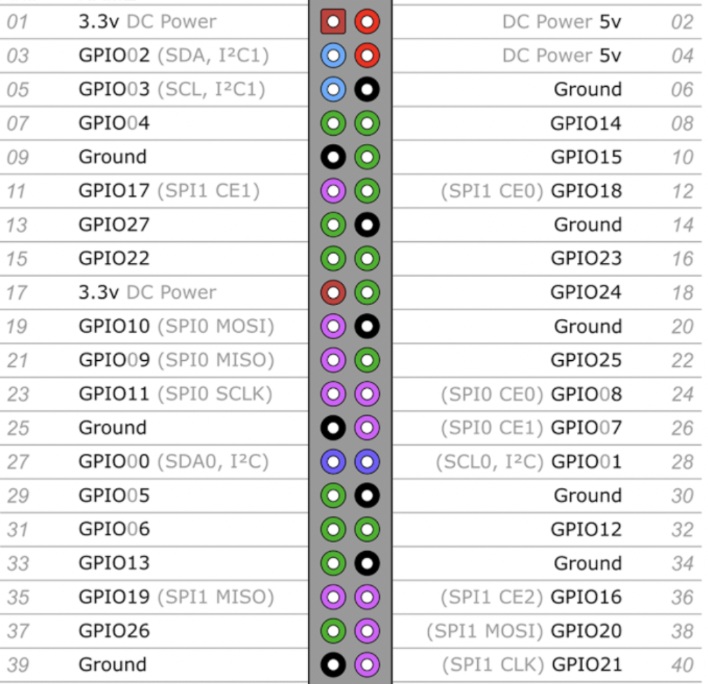
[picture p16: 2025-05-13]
doc/media/pinout.png

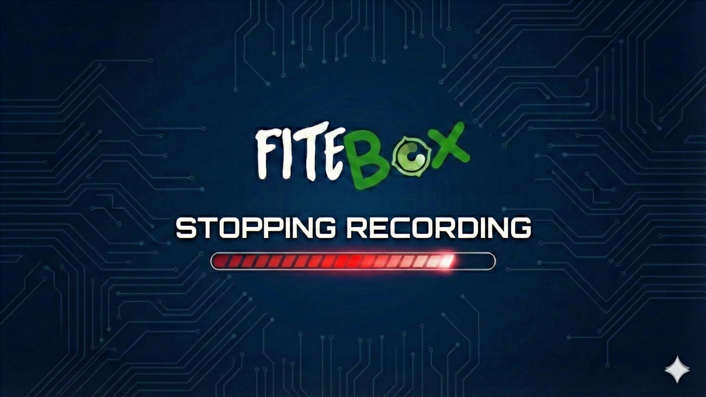
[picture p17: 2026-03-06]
images/img_recording_stop.png

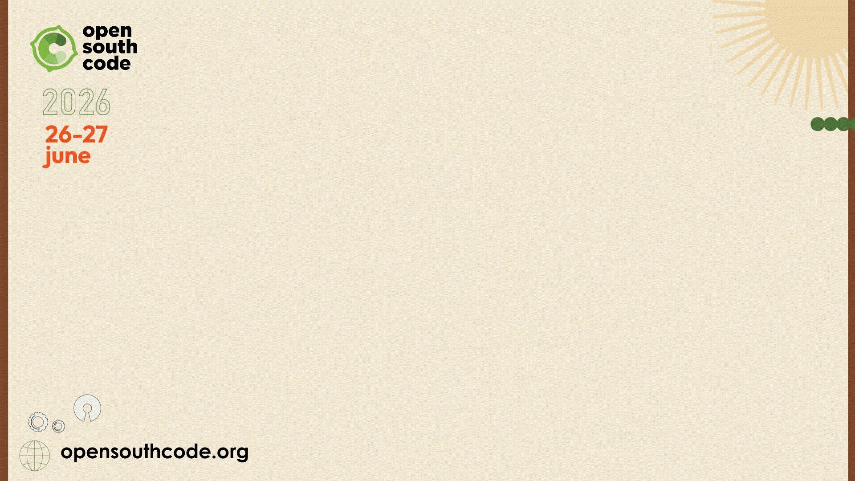
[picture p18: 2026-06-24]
doc/media/background26_1080p.png

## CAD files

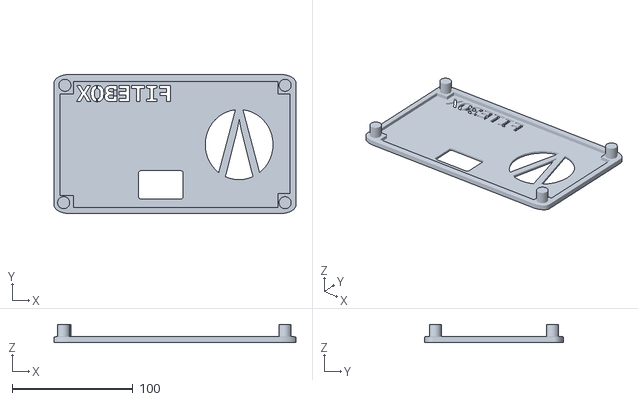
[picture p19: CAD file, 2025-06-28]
doc/case/case_top.stl
200.0 x 115.0 x 15.0

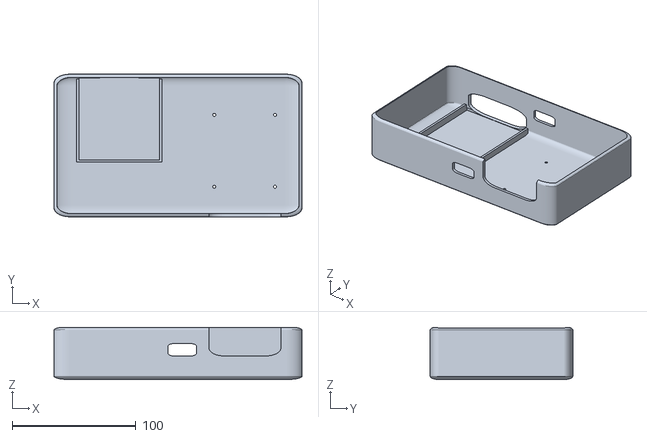
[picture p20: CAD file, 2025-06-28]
doc/case/case_bottom.stl
200.0 x 115.0 x 42.0

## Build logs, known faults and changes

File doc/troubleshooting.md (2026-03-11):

[← README](../README.md) · [Configuration](configuration.md) · [Recording](recording.md) · [Streaming](streaming.md) · [Recordings](recordings.md) · [Architecture](architecture.md) · 【 **Troubleshooting** 】 · [API](api.md) · [Diagnostics](diagnostics.md)

## Troubleshooting

### HDMI cable triggers insufficient power warning

Some bulky micro HDMI adapters or cables with thick molded connectors draw enough current to trigger the Raspberry Pi 5's under-voltage warning, even with the official power supply. The symptom is the lightning bolt icon and `vcgencmd get_throttled` showing under-voltage events. Use **slim, short micro HDMI cables** without bulky adapters. Before blaming your power supply, try swapping the HDMI cable.

### No video from HDMI capture

Check that the capture card is detected:

```bash
v4l2-ctl --list-devices
```

Look for "Hagibis" or "MS2109" in the output. If it does not appear, try a different USB port. Some USB 3.0 ports have compatibility issues - use USB 2.0.

### No audio

Some USB audio devices ship with capture channels **muted by default**. FITEBOX unmutes them automatically, but if you still have no audio:

```bash
# List ALSA cards
arecord -l

# Check mixer controls (replace 0 with your card number)
amixer -c 0 contents

# Force unmute everything
amixer -c 0 set Capture 100% unmute
amixer -c 0 set Mic 100% unmute
```

Also: **PulseAudio blocks ALSA**. If PulseAudio is running, FFmpeg cannot access audio devices directly. Kill it:

```bash
pulseaudio -k && sleep 1
```

In Docker, either do not install PulseAudio or kill it in the entrypoint.

### Recording has audio clicks (during streaming)

This is the MKV AAC timestamp problem. AAC packets in Matroska have micro-irregularities (on the order of milliseconds) that are inaudible during playback but produce clicks when copied directly to FLV/RTMP. The problem is amplified at segment transitions (intro→live→outro) where timestamps can go non-monotonic.

The fix is to **re-encode audio in the output process** (the single ffmpeg that sends to RTMP), not in the feeders:

```
Output process: -af aresample=async=1000 -c:a aac -b:a 192k
Feeders:        -c:a copy
```

`aresample=async=1000` aggressively corrects timestamp drift greater than ~21ms. It must be in the output process where the mpegts segments are joined, not in the feeders where the audio is already clean. FITEBOX handles this automatically in the streaming pipeline.

### Encoding speed below 1.0x

The Raspberry Pi 5 runs a single 1080p software encode at roughly 1.0x speed. If encoding speed drops below that, frames are being dropped. Check for:

- **Thermal throttling** - is the CPU temperature above 80°C? Add a fan or heatsink.
- **Disk contention** - is something else writing to the SSD? Preview extraction, downloads, and other disk access should use `nice -n 19 ionice -c 3`.
- **USB bus contention** - two capture devices plus an SSD on the same USB controller can saturate the bus.

### OLED not showing anything

```bash
# Check I2C is enabled
i2cdetect -y 1
# Should show 0x3c
```

If no device is found: check wiring (SDA→Pin 3, SCL→Pin 5, VCC→Pin 1, GND→Pin 39) and make sure I2C is enabled in `raspi-config`.

### USB device order changes between boots

This is normal. USB device enumeration is not deterministic - `/dev/video0` might be the webcam on one boot and the HDMI card on the next.

FITEBOX handles this automatically by detecting devices **by name** (looking for keywords like "Hagibis", "MS2109", "camera") rather than by device number. Do not hardcode `/dev/videoN` in any configuration.

### MKV file corrupted after power loss

MKV is designed to be crash-resistant. In most cases, the file is playable up to the point of interruption. If it needs repair:

```bash
# Install mkvtoolnix
sudo apt install mkvtoolnix

# Repair
mkclean --fix your_recording.mkv repaired.mkv
```

### YouTube stream dies after reconnection

YouTube needs a **1-2 minute cooldown** between stream sessions. If you stop and restart streaming too quickly, YouTube will accept the connection but degrade quality or drop it. Wait at least a minute before restarting.

[← README](../README.md) · [Configuration](configuration.md) · [Recording](recording.md) · [Streaming](streaming.md) · [Recordings](recordings.md) · [Architecture](architecture.md) · 【 **Troubleshooting** 】 · [API](api.md) · [Diagnostics](diagnostics.md)

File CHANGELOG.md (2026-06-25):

# Changelog

All notable changes to the FITEBOX project will be documented in this file.

The format is based on [Keep a Changelog](https://keepachangelog.com/en/1.1.0/).

## [1.4.5] - 2026-06-25

### Fixed
- Bumper upload no longer crashes with "list index out of range" when the
  uploaded video has no audio stream (empty ffprobe stream list).

### Changed
- Audio-less bumpers now get a silent stereo 48kHz track synthesized during
  conversion, so they can be spliced with the recording's audio when streaming.
- Audio-only files (no video stream) are now rejected early with a clear
  message instead of failing later with a cryptic ffmpeg error.

## [1.4.4] - 2026-06-23

### Added

- **Video detection module** (`src/detect_video.sh`): robustly resolves which `/dev/videoN` is the HDMI capture card vs the webcam, by USB ID then name, skipping UVC metadata nodes. Replaces the blind `/dev/video0` fallback that could steal the webcam node when no HDMI capture was present.

### Fixed

- **USB mic detection**: cheap USB-C audio dongles (TTGK `3302:00d1`, KM_B2 `001f:1601`) are now identified by USB ID instead of fragile ALSA name matching — the old `usb.*audio` pattern missed names like "KM_B2 Digital Audio at usb-…".
- **Capture capability check**: `card_has_capture` now trusts `arecord -l` (what can actually be captured) instead of the `/proc/asound` PCM node, so a card that registers without a usable capture stream is correctly skipped and a working mic is selected instead.
- **Silent recordings from USB dongles**: `force_unmute` now enables the ALSA capture switch (`set Capture cap` / `set Mic cap`). Many dongles boot with the capture toggle off, so the engine opened the device but recorded silence even with volume up and unmuted.
- **Audio lost after USB re-enumeration**: the container kept a stale device mapping (static `devices:` block resolved nodes at startup). It now live-mounts `/dev`, so cards that disconnect/reconnect stay visible without a restart.
- **Lint**: shellcheck `SC2181`/`SC2064`/`SC1091` in `recording_engine.sh`; pylint `C0103` (module-private globals via `good-names-rgxs`) and `W1404` (implicit string concat) in the web app.

### Changed

- All audio/video detection scripts and recording-engine comments translated to English (project convention).
- **docker-compose**: `/dev:/dev` live mount replaces the static `devices:` + `device_cgroup_rules` blocks.
- **README §5.4**: `make setup` is now mandatory before the first `make up` (it generates the TLS cert the proxy needs); fixed a broken section anchor.

## [1.2] - 2026-03-10

### Added

- **Display Server** (`fitebox_display.py`): Replaces Plymouth for HDMI output via `/dev/fb0`. Event-driven (0% CPU idle vs ~6% Plymouth). Numpy-accelerated RGB565. CLI + server mode
- **OLED Security settings**: Persistent config (`security.json`) with Web UI toggles: hide credentials, disable file deletion, lock network. Padlock icons on OLED.
- **Diagnostic notifications** on OLED and HDMI display when running Diagnostics from Web UI
- **Docker image publishing**: GHCR + Docker Hub support in Makefile
- **Type system**: `lib/types.py` with shared TypedDicts and type annotation fixes across codebase
- **Code quality**: Pre-commit config (black, isort, flake8, mypy, pylint, shellcheck, bandit)
- **Deploy directory** with production docker-compose and nginx config
- **Self-update system:** Auto-update from Web UI and OLED with two modes: official (Docker Hub pull) or local (git pull + docker build). Detects build mode via BUILD_MODE label baked into image. Check compares against remote (Docker Hub digest or git remote branch). Progress bar on OLED and HDMI display during update. Web UI shows current version with commit hash (local mode), available updates with commit count, and live progress bar during update. Container self-restarts after update; web auto-reloads when server comes back
- **Docker CLI, docker-compose plugin and git** added to container image for self-update support
- **Docker socket and project directory** mounted as volumes for container self-management

### Fixed

- **SIGTERM never reached Python**: `make` absorbed signals. Supervisor now launches Python directly, entrypoint forwards SIGTERM properly
- **OLED blanked on shutdown**: luma.oled cleanup disabled in signal handler to preserve shutdown message
- **Files menu empty on first open**: Now rebuilds when `recording_list` arrives via status update
- **Streaming audio fix (chipmunk/glitch)**: `aresample=async=1000` was applied in feeders where audio was already clean, causing artifacts. Moved to output process along with AAC re-encode, where it corrects non-monotonous DTS at intro→live→outro segment transitions in the mpegts pipe. Feeders now use `-c:a copy`. Added `+discardcorrupt` flag to output input parsing
- **Recording timer 7s ahead**: recording_start_time was set at engine launch instead of actual ffmpeg start. Now reads started_at from recording state file (`+1s buffer offset`)

### Changed

- Supervisor launches Python directly (no make wrappers), with `PYTHONUNBUFFERED=1` and `stopwaitsecs=10`
- Plymouth quit at boot, display daemon handles all runtime screens
- `helpers.py` sends to display daemon socket instead of calling `plymouth` binary
- Entrypoint forwards SIGTERM to supervisord instead of `exit 0`
- Dockerfile adds `python3-numpy`, compose adds `images/` volume

## [1.1] - 2026-03-07

### Changed
- Full linting pass and comprehensive code review across all Python modules
- Added type annotations throughout codebase
- General code cleanup and formatting consistency

### Added
- Docker Hub image publishing support (`br0th3r/fitebox`)
- GitHub Container Registry (GHCR) publishing support
- Expanded documentation
- Full system end-to-end testing

## [1.0] - 2026-03-06

FITEBOX v1.0 — first production release

This commit marks the first production-ready version of FITEBOX
after a complete redesign.

The new system was built in 11 days using a lean build–test–iterate
approach, focusing on simplicity, reliability, and real conference
deployment needs.

From this point on, FITEBOX moves from experimental prototype
to a stable platform ready to record real events.

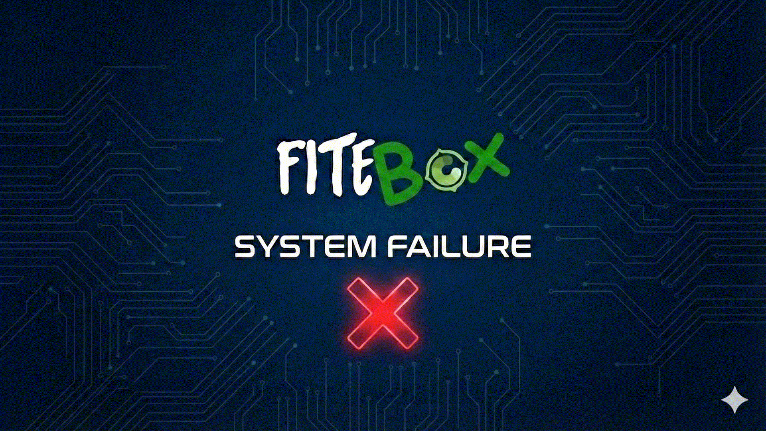
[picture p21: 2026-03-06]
images/img_failure.png

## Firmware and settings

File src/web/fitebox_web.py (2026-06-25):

#!/usr/bin/env python3  # pylint: disable=too-many-lines
"""
FITEBOX Web Server v1.0
FastAPI + Jinja2 + WebSocket interface for FITEBOX recording system
Connects to fitebox_manager via the same Unix socket as OLED controller
"""

import asyncio
import io
import json
import logging
import os
import platform
import re
import shutil
import subprocess
import sys
import tempfile
import time
import urllib.request as ureq
import xml.etree.ElementTree as ET  # noqa:N817
from asyncio.subprocess import Process
from collections import deque
from datetime import datetime, timezone
from ipaddress import IPv4Network
from pathlib import Path
from typing import Any, AsyncGenerator, cast

from typing_extensions import TypedDict

# isort: split

import qrcode  # pylint: disable=import-error
import qrcode.image.svg  # pylint: disable=import-error
from fastapi import (  # type: ignore # pylint: disable=import-error # noqa: E501
    Depends,
    FastAPI,
    File,
    HTTPException,
    Query,
    Request,
    UploadFile,
    WebSocket,
    WebSocketDisconnect,
)
from fastapi.concurrency import (  # type: ignore # pylint: disable=import-error # noqa: E501
    run_in_threadpool,
)
from fastapi.responses import (  # type: ignore # pylint: disable=import-error # noqa: E501
    FileResponse,
    HTMLResponse,
    RedirectResponse,
    Response,
    StreamingResponse,
)
from fastapi.staticfiles import (  # type: ignore # pylint: disable=import-error # noqa: E501
    StaticFiles,
)
from fastapi.templating import (  # type: ignore # pylint: disable=import-error # noqa: E501
    Jinja2Templates,
)
from helpers import (  # type: ignore # pylint: disable=import-error # noqa: E501
    load_or_generate_key,
    verify_signature,
)
from manager import (  # type: ignore # pylint: disable=import-error # noqa: E501
    ManagerSocketClient,
)

from lib import settings
from lib.helpers import (
    OutScreen,
    _send_display_message,
    announce_screen,
    out_screen,
)
from lib.schedule_parser import (  # type: ignore # pylint: disable=import-error # noqa: E501
    get_rooms,
)

# === CONFIGURATION ===
MASTER_KEY_FILE = "config/master.key"
KEY_FILE = settings.WEB_KEY_FILE
STREAM_CONFIG_FILE = "/fitebox/data/stream_config.json"
RECORDINGS_DIR = "/recordings"
WEB_PORT = 8080
SIGNATURE_MAX_AGE = 30  # seconds tolerance for replay protection
YOUTUBE_CONFIG_FILE = "/tmp/fitebox_youtube.json"
SIMULATION = os.getenv("FITEBOX_SIMULATION", "0") == "1"
SECURITY_FILE = "/fitebox/data/security.json"
_SECURITY_DEFAULTS: dict[str, bool] = {
    "hide_credentials": False,
    "disable_delete": False,
    "disable_network": False,
}

logger = logging.getLogger(__name__)

DOCKER_IMAGE_REPO = "br0th3r/fitebox"
BOOT_JSON = Path("/fitebox/data/boot.json")


def _read_boot_json() -> dict[str, Any]:
    """Read boot.json safely. Returns {} if missing, empty or corrupt."""
    try:
        text = BOOT_JSON.read_text(encoding="utf-8").strip()
        if text:
            return json.loads(text)
    except Exception:
        pass
    return {}


def _write_boot_json(
    updates: dict[str, Any],
    remove_keys: list[str] | None = None,
) -> None:
    """
    Merge updates into boot.json preserving unrelated keys.
    Keys in remove_keys are deleted from the result.
    """
    data = _read_boot_json()
    data.update(updates)
    for key in remove_keys or []:
        data.pop(key, None)
    try:
        BOOT_JSON.write_text(json.dumps(data), encoding="utf-8")
    except Exception as e:
        logger.warning(f"Could not write boot.json: {e}")


# Pull state: tracks active background pulls
_pull_state: dict[str, Any] = {
    "active": False,
    "tag": None,
    "percent": 0,
    "message": "",
    "error": None,
}
if SIMULATION:
    logger.warning(
        "⚠️  Running in SIMULATION mode - no actual manager connection",
    )

# Paths (adjusted for Docker vs Host)
BASE_DIR = Path(__file__).parent
TEMPLATES_DIR = BASE_DIR / "templates"
STATIC_DIR = BASE_DIR / "statics"

# Load/generate shared key for HMAC authentication with JS client
time.sleep(1)
SHARED_KEY = load_or_generate_key(KEY_FILE)
SHARED_MASTER_KEY = load_or_generate_key(MASTER_KEY_FILE)
print(f"🔑 Web key: {SHARED_KEY}")


# Types
class NetHistoryRates(TypedDict):
    ts: float
    wlan_rx: float
    wlan_tx: float
    eth_rx: float
    eth_tx: float


class NetRate(TypedDict):
    rx_rate: float
    tx_rate: float


class NetRates(TypedDict):
    wlan0: NetRate
    eth0: NetRate


class WebMetricsSnapshot(TypedDict):
    cpu: float
    temp: float
    net_rates: NetRates


class StatusHistoryData(TypedDict):
    ts: float
    cpu: float
    temp: float


class MemInfo(TypedDict):
    ram_used_mb: float
    ram_total_mb: float
    swap_used_mb: float
    swap_total_mb: float


class DiskIOInfo(TypedDict):
    io_read_kbs: float
    io_write_kbs: float


class VitalsIOInfo(TypedDict):
    ts: float
    read_sectors: float
    write_sectors: float


class UpdateResult(TypedDict):
    mode: str  # "none", "update", "error"
    current_version: str
    update_available: bool
    is_prerelease: bool
    latest_version: str | None
    commits_behind: int | None
    latest_commit: str | None
    error: str | None


class UpdateState(TypedDict):
    running: bool
    phase: str  # checking, pulling, building, restarting
    percent: int
    message: str
    error: str
    available: UpdateResult | None


class RecRemainingInfo(TypedDict):
    rec_remaining_min: float | None
    rec_measured: bool


class IP4(TypedDict):
    ip: str
    netmask: str
    gateway: str
    dns: str


class WifiInfo(TypedDict):
    connected: bool
    enabled: bool
    ssid: str
    ip: str
    netmask: str
    gateway: str
    dns: str
    mode: str
    signal: int
    password: str
    mac: str
    dhcp: bool


class EthInfo(TypedDict):
    connected: bool
    enabled: bool
    ip: str
    netmask: str
    gateway: str
    dns: str
    mac: str
    dhcp: bool


class NetInfo(TypedDict):
    wifi: WifiInfo
    ethernet: EthInfo


class NetInfoCache(TypedDict):
    ts: float
    data: NetInfo | None


class WifiNetwork(TypedDict):
    ssid: str
    signal: str
    security: str


class PipelineConfig(TypedDict):
    destination: str  # youtube, twitch, custom
    quality: str  # 1080p, 720p, etc.
    stream_key: str | None  # for youtube/twitch
    rtmp_url: str | None  # for custom
    enabled: bool


class StreamingState(TypedDict):
    streaming_active: bool
    streaming_draining: bool
    streaming_phase: str  # waiting, buffering, intro, live, draining, outro


class StreamingStateFull(StreamingState):
    streaming_dest: str | None
    streaming_quality: str | None


class V4L2DeviceInfo(TypedDict):
    dev: str
    name: str
    type: str
    size: str
    audio_card: str | None
    audio_dev: str | None


class AudioCardInfo(TypedDict):
    id: str
    name: str
    dev: str
    selected: str | None
    role: str  # input, output, unknown


class DetectedDevices(TypedDict):
    video: list[V4L2DeviceInfo]
    audio: list[AudioCardInfo]
    selection: dict[str, str]


class HealthSample(TypedDict):
    status: str
    time: float
    frame: int
    fps: float | None
    size_kb: int | None
    speed: float | None


class RecordingMetadata(TypedDict):
    version: int
    recording_started: str
    recording_finished: str | None
    duration_sec: float | None
    title: str
    author: str
    session: dict[str, Any]
    devices: dict[str, Any]
    histogram: dict[str, Any]
    streamed: bool
    downloaded: bool
    file_size_bytes: int
    last_update: str
    backfilled: bool


class PreviewInfo(DetectedDevices):
    status: str


class PreviewCache(TypedDict):
    devices: DetectedDevices | None
    ts: float


class DockerLocalImage(TypedDict):
    image_id: str
    size: str
    digest: str
    created_at: str


class DockerRemoteImage(TypedDict):
    digest: str
    pushed_at: str
    size: str | None


class DockerImage(TypedDict):
    tag: str
    downloaded: bool
    in_use: bool
    is_latest: bool
    is_stable: bool
    deletable: bool
    size: str | None
    hub_size: str | None
    image_id: str | None
    created_at: str | None
    digest: str | None


# --- Web UI Responses ---


class SystemVitalsResponse(MemInfo, DiskIOInfo, RecRemainingInfo):
    ping_ms: float | None


class DashboardResponse(SystemVitalsResponse):
    cpu_history: list[StatusHistoryData]
    net_history: list[NetHistoryRates]


class RecordingStartResponse(TypedDict):
    status: str
    message: str
    streaming: bool | None


class RecordingStopResponse(TypedDict):
    status: str
    message: str
    streaming_draining: bool | None


class RecordingTitleResponse(TypedDict):
    status: str
    message: str


class NetworkScanResponse(TypedDict):
    status: str
    networks: list[WifiNetwork]


class StreamingProgressResponse(TypedDict):
    active: bool
    phase: str
    draining: bool


class StreamingProgressFullResponse(StreamingProgressResponse):
    position: float  # seconds
    total: float  # seconds
    percent: float
    remaining_mb: float
    file: str | None


class ErrorResponse(TypedDict):
    status: str
    message: str


# --- System vitals (polled by dashboard) ---

_vitals_io_prev: VitalsIOInfo | None = None
_vitals_ping_ms: float | None = None
_vitals_ping_task: asyncio.Task[Any] | None = None

# --- System metrics history (ring buffer, server-side) ---
# 120 entries × ~5s interval ≈ 10 minutes of history
_METRICS_HISTORY_MAX = 120
_metrics_history: deque[StatusHistoryData] = deque(
    maxlen=_METRICS_HISTORY_MAX,
)
_metrics_net_history: deque[NetHistoryRates] = deque(
    maxlen=_METRICS_HISTORY_MAX,
)

# --- Update system ---
BUILD_MODE_FILE = Path("/app/BUILD_MODE")
PROJECT_DIR = "/fitebox/project"
COMPOSE_FILE = f"{PROJECT_DIR}/docker-compose.yml"

_update_state: UpdateState = {
    "running": False,
    "phase": "",  # checking, pulling, building, restarting
    "percent": 0,
    "message": "",
    "error": "",
    "available": None,  # result of last check
}

# --- Recording bitrate estimation ---
_FALLBACK_BITRATE_BPS = 800_000  # ~800 KB/s if no recordings exist
_worst_bitrate_bps: float = _FALLBACK_BITRATE_BPS
_worst_bitrate_ready = False  # pylint: disable=invalid-name

# --- Network Info (reads real OS state via nmcli/ip) ---
_net_info_cache: NetInfoCache = {"data": None, "ts": 0}
_NET_INFO_TTL = 60  # seconds (IPs/SSIDs don't change frequently)

# --- System ---
BACKGROUND_DIR = Path("/fitebox/data")
BACKGROUND_FILE = BACKGROUND_DIR / "background_1080p.png"
BACKGROUND_FALLBACK = BASE_DIR / "background_1080p.png"  # shipped default

DIAG_COMMANDS = {
    "system": (
        "echo '--- OS ---'; uname -a; echo '';"
        "echo '--- Hardware ---'; grep Model /proc/cpuinfo "
        "2>/dev/null || echo 'N/A'; echo '';"
        "echo '--- Memory ---'; free -h; echo '';"
        "echo '--- Disk ---'; df -h /recordings "
        "2>/dev/null || df -h /; echo '';"
        "echo '--- Uptime ---'; uptime; echo '';"
        "echo '--- Temperature ---'; vcgencmd measure_temp "
        "2>/dev/null || echo 'vcgencmd not available'; echo '';"
        "echo '--- Throttling ---'; vcgencmd get_throttled "
        "2>/dev/null || echo 'vcgencmd not available'; echo '';"
        "echo '--- Supervisor ---'; supervisorctl status "
        "2>/dev/null || echo 'supervisor not running'"
    ),
    "video": (
        "echo '--- Video Detection ---'; /app/detect_video.sh 2>&1; echo '';"
        "echo '--- V4L2 Devices ---'; v4l2-ctl --list-devices 2>&1; echo '';"
        "echo '--- /dev/video ---'; ls -la /dev/video* 2>&1; echo '';"
        "for d in /dev/video*; do "
        '  echo "--- $d capabilities ---"; '
        "  v4l2-ctl -d $d --all 2>&1 | head -20; echo ''; "
        "done"
    ),
    "audio": (
        "echo '--- Audio Detection ---'; /app/detect_audio.sh 2>&1; echo '';"
        "echo '--- ALSA Devices ---'; arecord -l 2>&1; echo '';"
        "echo '--- Sound Cards ---'; cat /proc/asound/cards 2>&1; echo '';"
        "echo '--- Audio Levels ---';"
        "for c in 0 1 2 3 4; do "
        "  amixer -c $c info >/dev/null 2>&1 && "
        'echo "Card $c:" && amixer -c $c '
        "2>/dev/null | grep 'Simple mixer control' | head -5; "
        "done; echo '';"
        "echo '--- PulseAudio ---'; pgrep -x pulseaudio >/dev/null "
        "&& echo '⚠️  PulseAudio RUNNING' || echo '✅ PulseAudio not running'"
    ),
    "oled": (
        "echo '--- I2C Bus ---'; i2cdetect -y 1 2>&1; echo '';"
        "echo '--- I2C Devices ---'; ls -la /dev/i2c-* 2>&1; echo '';"
        "echo '--- OLED Controller ---'; pgrep -a oled_controller "
        "2>&1 || echo '❌ oled_controller not running'; echo '';"
        "echo '--- Python luma.oled ---'; python3 -c 'import luma.oled; "
        'print("✅ luma.oled OK")\' '
        "2>&1 || echo '❌ luma.oled not installed'"
    ),
    "gpio": (
        "echo '--- GPIO Chips ---'; ls -la /dev/gpiochip* 2>&1; echo '';"
        "echo '--- Buttons Controller ---'; pgrep -a buttons "
        "2>&1 || echo '❌ buttons controller not running'; echo '';"
        "echo '--- GPIO Lines (pins 16,19,20,26) ---'; "
        "for pin in 16 19 20 26; do "
        '  info=$(gpioinfo /dev/gpiochip0 2>/dev/null | grep "line  *$pin:"); '
        '  if [ -n "$info" ]; then echo "  $info"; '
        '  else echo "  Pin $pin: not found"; fi; '
        "done 2>&1 || echo 'gpioinfo not available'"
    ),
    "network": (
        "echo '--- Interfaces ---'; ip -br addr show 2>&1; echo '';"
        "echo '--- Routes ---'; ip route 2>&1; echo '';"
        "echo '--- DNS ---'; cat /etc/resolv.conf 2>&1; echo '';"
        "echo '--- Internet (IP) ---'; "
        "if command -v ping >/dev/null 2>&1; then "
        "ping -c 2 -W 2 8.8.8.8 2>&1; "
        "else curl -sS --max-time 3 -o /dev/null -w 'HTTP %{http_code} in "
        "%{time_total}s to %{remote_ip}' http://1.1.1.1 "
        "2>&1 || echo '❌ No connectivity'; fi; echo '';"
        "echo '--- Internet (DNS) ---'; "
        "if command -v ping >/dev/null 2>&1; then "
        "ping -c 2 -W 2 google.com 2>&1; "
        "else curl -sS --max-time 3 -o /dev/null -w 'HTTP %{http_code} in "
        "%{time_total}s (%{remote_ip})' http://google.com "
        "2>&1 || echo '❌ DNS resolution failed'; fi; echo '';"
        "echo '--- WiFi ---'; "
        "if command -v iwconfig >/dev/null 2>&1; then iwconfig wlan0 2>&1; "
        "elif command -v iw >/dev/null 2>&1; then iw dev wlan0 info 2>&1; "
        "else ip link show wlan0 2>&1 || echo 'No wlan0'; fi"
    ),
}

# --- Streaming Pipeline (intro → recording → outro) ---

_RTMP_PRESETS = {
    "youtube": "rtmp://a.rtmp.youtube.com/live2",
    "twitch": "rtmp://live.twitch.tv/app",
}
_KEY_PATTERNS = {
    "youtube": re.compile(r"^[a-zA-Z0-9_-]{4,}(-[a-zA-Z0-9_-]{4,}){0,4}$"),
    "twitch": re.compile(r"^live_[a-zA-Z0-9_]{10,}$"),
}

BUMPER_INTRO_FILE = BACKGROUND_DIR / "bumper_intro.mp4"
BUMPER_OUTRO_FILE = BACKGROUND_DIR / "bumper_outro.mp4"
_BUMPER_MAP = {"intro": BUMPER_INTRO_FILE, "outro": BUMPER_OUTRO_FILE}
_BUMPER_VIDEO_EXTS = (".mp4", ".mkv", ".mov", ".avi", ".webm")


# Active pipeline state
_pipeline_task: asyncio.Task[Any] | None = None
_pipeline_procs: list[Process] = []  # running subprocess refs for cleanup
_pipeline_stop_event: asyncio.Event | None = None
_pipeline_config: PipelineConfig | None = None  # active stream config
_pipeline_phase: str = ""  # waiting, buffering, intro, live, draining, outro
_pipeline_draining = False  # pylint: disable=invalid-name

# --- Preview (hardware check when not recording) ---
_preview_cache: PreviewCache = {"devices": None, "ts": 0}

# Track stream ffmpeg processes for cleanup
_preview_stream_procs: dict[str, Any] = {}  # source -> Process

# --- Recording Health Histogram ---
# Parses ffmpeg stderr log for frame/fps/speed anomalies.
# Log uses \r for progress lines (no \n), so we split on 'frame=' boundaries.

FFMPEG_LOG_PATH = Path("/fitebox/log/fitebox_ffmpeg.log")
_HEALTH_BUCKETS = 200  # max segments in histogram

_PROGRESS_RE = re.compile(
    r"frame=\s*(\d+)\s+fps=\s*([\d.]+)\s+q=[\d.-]+\s+size=\s*(\d+)kB\s+"
    r"time=(\d+:\d+:\d+\.\d+)\s+bitrate=\s*([\d.]+)kbit",
)
_SPEED_RE = re.compile(r"speed=\s*([\d.]+)x")

# Delta parsing state - avoids re-reading entire log on each poll
_health_log_offset: int = 0
_health_cached_samples: list[HealthSample] = []
_health_log_path_cached: str = ""

# --- Recording Metadata ---
# JSON sidecar file alongside each .mkv with session info, histogram, tags.
# Written every 10s during recording, finalized on stop.

HEALTH_FILE = Path("/fitebox/run/fitebox_health.json")
_META_WRITER_INTERVAL = 10  # seconds
_meta_writer_task: asyncio.Task[None] | None = None
_meta_current_file: str = ""  # track which recording we're writing metadata for

# --- On-demand Recording Thumbnail ---
# Extracts a frame from the active recording every N seconds.
# Zero CPU impact - sandwich approach: head 1M + tail 10M →
# ffprobe keyframes → output-seek 5s clip.
PREVIEW_CLIP_PATH = Path("/fitebox/run/rec_preview.mp4")
SANDWICH_PATH = Path("/fitebox/run/rec_sandwich.mkv")

# --- Preview refresh ---
PREVIEW_REFRESH_INTERVAL = 15
_last_preview_ts: float = 0


# --- Bumper concatenation (offline, not during recording) ---
_bumper_concat_lock = asyncio.Lock()


# === MJPEG Streaming (continuous, zero re-encode) ===

# Preview sizes - MUST match native MJPEG resolutions to avoid transcoding.
# Hagibis supports 1280x720, 640x480 etc. Angetube supports 640x480.
# Using 640x480 for both guarantees -c:v copy (zero CPU).
_PREVIEW_SIZES = {"hdmi": "640x480", "cam": "640x480"}


# === APP LIFECYCLE ===

manager_client = ManagerSocketClient(
    settings.SOCKET_PATH,
    simulation=SIMULATION,
)


def _read_security() -> dict[str, bool]:
    """Read security settings from persistent file."""
    try:
        with open(SECURITY_FILE, encoding="utf-8") as f:
            data = json.load(f)
        return {**_SECURITY_DEFAULTS, **data}
    except (FileNotFoundError, json.JSONDecodeError):
        return dict(_SECURITY_DEFAULTS)


def _write_security(current: dict[str, bool]) -> None:
    """Write security to persistent file."""
    clean = {k: current.get(k, v) for k, v in _SECURITY_DEFAULTS.items()}
    with open(SECURITY_FILE, "w", encoding="utf-8") as f:
        json.dump(clean, f, indent=2)


def _cleanup_stale_state():
    """Remove stale state files from /fitebox/run on startup.
    Prevents ghost 'recording' status from previous container lifecycle."""
    run_dir = Path("/fitebox/run")
    stale_files = [
        "fitebox_health.json",
        "fitebox_ffmpeg.pid",
        "rec_preview.mp4",
        "rec_sandwich.mkv",
    ]
    for fname in stale_files:
        f = run_dir / fname
        if f.exists():
            logger.info(f"🧹 Removing stale state file: {f}")
            f.unlink(missing_ok=True)


async def lifespan(
    app: FastAPI,  # pylint: disable=unused-argument, redefined-outer-name
) -> AsyncGenerator[
    None,
    None,
]:  # pylint: disable=unused-argument, redefined-outer-name
    """Startup/shutdown."""
    global _vitals_ping_task, _meta_writer_task  # pylint: disable=global-statement # noqa: E501
    # Clean state from previous run
    _cleanup_stale_state()
    # Connect to manager socket
    connected = await manager_client.connect()
    if not connected:
        logger.warning("⚠️  Starting without manager connection (will retry)")
        asyncio.create_task(manager_client.auto_reconnect())
    # Background ping for vitals
    _vitals_ping_task = asyncio.create_task(_ping_loop())
    # Register metrics history callback (populates ring buffer for charts)
    manager_client.on_status(_record_metrics_sample)
    # Scan existing recordings for worst-case bitrate
    # estimate (background, non-blocking)
    asyncio.create_task(_scan_worst_bitrate())
    # Recording metadata writer (updates JSON sidecar every 10s)
    _meta_writer_task = asyncio.create_task(_metadata_writer_loop())
    # Backfill metadata for existing recordings (non-blocking)
    asyncio.create_task(_backfill_metadata())
    yield
    if _vitals_ping_task:
        _vitals_ping_task.cancel()
    if _meta_writer_task:
        _meta_writer_task.cancel()
    await manager_client.disconnect()


# === FASTAPI APP ===

app = FastAPI(title="FITEBOX Web", lifespan=lifespan)
app.mount("/statics", StaticFiles(directory=str(STATIC_DIR)), name="statics")
templates = Jinja2Templates(directory=str(TEMPLATES_DIR))


# === Build mode (official vs local) ===
def _get_build_mode() -> str:
    """Read build mode: 'official' or 'local'."""
    try:
        return BUILD_MODE_FILE.read_text(encoding="utf-8").strip()
    except Exception:
        return "local"


# === System info (cached at startup) ===
_system_info: dict[str, str] = {}
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

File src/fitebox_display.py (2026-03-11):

#!/usr/bin/env python3
"""
FITEBOX Display Server v1.0
Manage display on HDMI via /dev/fb0.

Protocol (JSON lines):
    {"screen": "ready"}
    {"screen": "failure", "text": "FFmpeg failed"}
    {"text": "Custom message only"}
"""

import json
import os
import signal
import socket
import sys
import textwrap
import threading
import time
from datetime import datetime
from pathlib import Path

import numpy as np
from PIL import Image, ImageDraw, ImageFont

from lib import settings

# === CONFIGURATION ===

DISPLAY_SOCKET = os.path.join(settings.RUN_DIR, "fitebox_display.sock")
FRAMEBUFFER = "/dev/fb0"
IMAGE_DIR = Path(os.environ.get("FITEBOX_DISPLAY_IMAGES", "/app/images"))
FONT_DIR = Path(os.environ.get("FITEBOX_FONT_DIR", "/app/fonts"))

# Screen name → image filename mapping
SCREEN_IMAGES = {
    "boot": "img_boot.png",
    "ready": "img_ready.png",
    "recording": "img_recording.png",
    "recording_start": "img_recording_start.png",
    "recording_stop": "img_recording_stop.png",
    "shutdown": "img_shutdown.png",
    "off": "img_off.png",
    "failure": "img_failure.png",
}

# Text rendering
TEXT_FONT_NAME = "DejaVuSansMono.ttf"
TEXT_FONT_SIZE = 50
TEXT_COLOR = (255, 255, 255, 255)  # White
TEXT_Y_PERCENT = 0.85  # Position at 80% of screen height


class FiteboxDisplay:  # pylint: disable=too-many-instance-attributes
    """Framebuffer display server."""

    def __init__(self):
        self.running = True
        self.fb_width = 0
        self.fb_height = 0
        self.fb_bpp = 0
        self.fb_stride = 0
        self.fb_available = False

        # Pre-loaded images (screen_name → bytes ready for fb0)
        self._image_cache: dict[str, bytes] = {}
        self._pil_cache: dict[str, Image.Image] = {}
        self._black_frame: bytes = b""
        self._black_image: Image.Image | None = None
        self._font: ImageFont.FreeTypeFont | ImageFont.ImageFont | None = None
        self._font_announce: (
            ImageFont.FreeTypeFont | ImageFont.ImageFont | None
        ) = None
        self._current_screen = ""

        # Overlay (announce) state
        self._overlay_active = False
        self._overlay_flashing = False
        self._overlay_timer: threading.Timer | None = None
        self._overlay_frame_bright: bytes = b""
        self._overlay_frame_dim: bytes = b""
        self._pending_screen: str = ""
        self._pending_text: str = ""

        # Detect framebuffer
        self._detect_framebuffer()
        if self.fb_available:
            self._load_font()
            self._preload_images()
            self._clear_screen()
            print(
                f"📺 Framebuffer ready: {self.fb_width}x{self.fb_height} "
                f"@ {self.fb_bpp}bpp",
            )
        else:
            print("⚠️  No framebuffer available, running in headless mode")

    def _detect_framebuffer(self) -> None:
        """Read framebuffer properties from sysfs."""
        try:
            if not os.path.exists(FRAMEBUFFER):
                return

            fb_sys = Path("/sys/class/graphics/fb0")

            with open(fb_sys / "virtual_size", encoding="utf-8") as f:
                parts = f.read().strip().split(",")
                self.fb_width = int(parts[0])
                self.fb_height = int(parts[1])

            with open(fb_sys / "bits_per_pixel", encoding="utf-8") as f:
                self.fb_bpp = int(f.read().strip())

            with open(fb_sys / "stride", encoding="utf-8") as f:
                self.fb_stride = int(f.read().strip())

            if self.fb_width > 0 and self.fb_height > 0 and self.fb_bpp >= 16:
                self.fb_available = True
        except Exception as e:
            print(f"⚠️  Framebuffer detection failed: {e}")

    def _load_font(self) -> None:
        """Load font for text rendering."""
        font_path = FONT_DIR / TEXT_FONT_NAME
        font: ImageFont.FreeTypeFont | ImageFont.ImageFont | None = None
        try:
            if font_path.exists():
                font = ImageFont.truetype(str(font_path), TEXT_FONT_SIZE)
                print(f"📝 Font loaded: {TEXT_FONT_NAME}")
            else:
                # Try system DejaVu
                for sys_path in [
                    "/usr/share/fonts/truetype/dejavu/DejaVuSansMono.ttf",
                    "/usr/share/fonts/truetype/dejavu/DejaVuSans.ttf",
                ]:
                    if os.path.exists(sys_path):
                        self._font = ImageFont.truetype(
                            sys_path,
                            TEXT_FONT_SIZE,
                        )
                        print(f"📝 Font loaded: {sys_path}")
                        return
                font = ImageFont.load_default()
                print("📝 Using default font")
        except Exception as e:
            font = ImageFont.load_default()
            print(f"⚠️  Font load error, using default: {e}")
        self._font = font

        # Large font for announcements (3x)
        try:
            if font and hasattr(self._font, "path"):
                # If we have a truetype font, load a larger version
                # for announcements
                font = ImageFont.truetype(
                    self._font.path,
                    TEXT_FONT_SIZE * 3,
                )
        except Exception:
            pass
        self._font_announce = font  # type: ignore[assignment]

    def _image_to_fb_bytes(self, img: Image.Image) -> bytes:
        """Convert PIL Image to framebuffer byte format.

        RPi5 fb0 is typically XRGB8888 (32bpp): bytes are B, G, R, X per pixel.
        """
        # Ensure correct size
        if img.size != (self.fb_width, self.fb_height):
            img = img.resize(
                (self.fb_width, self.fb_height),
                Image.Resampling.LANCZOS,
            )

        img = img.convert("RGBA")

        if self.fb_bpp == 32:
            # RGBA → BGRA (swap R and B channels for framebuffer)
            r, g, b, a = img.split()
            img = Image.merge("RGBA", (b, g, r, a))
            return img.tobytes()

        elif self.fb_bpp == 16:
            # RGB565 - vectorized with numpy
            rgb = np.frombuffer(
                img.convert("RGB").tobytes(),
                dtype=np.uint8,
            ).reshape(-1, 3)
            ch_r = rgb[:, 0].astype(np.uint16)
            ch_g = rgb[:, 1].astype(np.uint16)
            ch_b = rgb[:, 2].astype(np.uint16)
            rgb565 = ((ch_r >> 3) << 11) | ((ch_g >> 2) << 5) | (ch_b >> 3)
            return rgb565.astype("<u2").tobytes()
        else:
            # Fallback: raw RGBA
            return img.tobytes()
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

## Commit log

2025-05-02 Last frame removed
2025-05-12 warmup button
2025-05-12 initial buttons uplaod
2025-05-13 pinout and initial button controller
2025-06-13 Improved device detection for the OLED controller
2026-03-06 FITEBOX v1.0
    [case_bottom.stl, case_top.stl]
2026-03-16 fix: remove images volume mount in production compose, images are baked into the Docker image
2026-03-16 fix: font size for web ui key on oled scren, fix: upgrade system with official images, added: documentation for quick install, feature: install script to support custom versions
    [fitebox_web.py, oled_controller.py]
2026-03-17 fix: gitlab workflow to protect latest docker image from beging used with non stable images, fix: docker image management
    [fitebox_web.py]
2026-03-17 added: info about upgrade system, fixed: upgrading system
    [fitebox_web.py]
2026-03-19 fixed: remove old images from docker during restart
    [fitebox_web.py]
2026-06-23 Release 1.4.4: USB audio detection & capture fixes, /dev live-mount, lint, docs
    [fitebox_web.py]
2026-06-25 fix(bumper): handle audio-less uploads, reject audio-only (1.4.5)
    [fitebox_web.py]
